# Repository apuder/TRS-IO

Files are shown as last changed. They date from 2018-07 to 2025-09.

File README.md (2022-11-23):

# TRS-IO

TRS-IO gives a TRS-80 Model 1/III online capabilities and provides
access to a variety of services. TRS-IO currently features the
following capabilities:

1. Access to the <a href="https://retrostore.org">RetroStore</a>
2. <a href="http://frehd.com">FreHD</a> emulation
3. Access to files mounted on a SMB share or located on a micro-SD card
4. Access to remote servers via TCP
5. Virtual printer support

The TRS-IO versions for the Model 1 and Model III have some additional features that
are explained below. The following sections give an overview of TRS-IO as well as setup
instructions. This Github repository contains the complete source code
as well as the KiCad schematics for the PCB (Printed Circuit Board).
For the following descriptions it is assumed that an assembled TRS-IO
card is available.

### Overview

The figure below depicts the overall architecture. The TRS-80 machine
is connected to TRS-IO via the I/O bus.  TRS-IO has a WiFi module that
connects to the local WiFi router. This allows TRS-IO to connect to
the Internet and access various services. Note that TRS-IO can only
connect to a 2.4 GHz WiFi network. It is recommended to use an IPEX
antenna to improve WiFi reception.

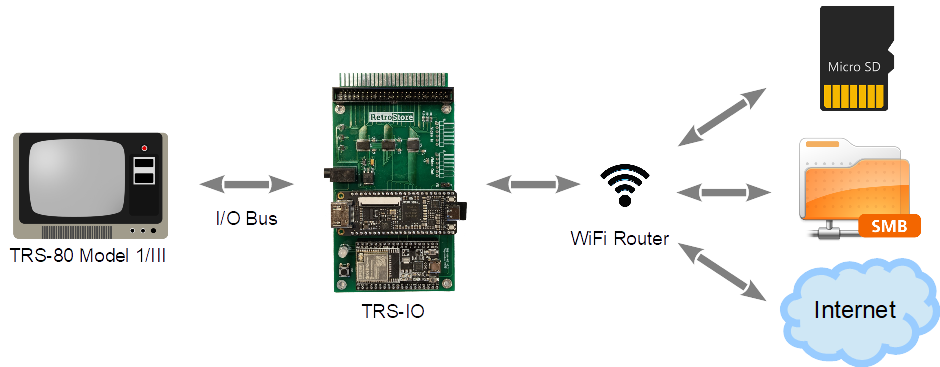
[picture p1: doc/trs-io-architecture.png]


### Prerequisites

TRS-IO requires a TRS-80 Model III with 48kB of RAM or a Model 1 with 16kB of RAM.
Floppy disk drives or a cassette tape are not required.

### Power Supply

There are two versions of TRS-IO that are tailored to the Model 1 and Model III. Each version makes use of an ESP32 microcontroller
as well as a Tang Nano 9K FPGA. Both the ESP32 microcontroller as well as the Nano 9K need to be powered. There are two ways of doing
this.

* Power each module independently via two USB cables that connect to the ESP32's micro-USB and the Nano 9K's USB-C connector.
  For this option, the "VU" jumper (mentioned below), <b>SHOULD NOT BE USED</b>.
* Power the ESP32 via the Nano 9K or vice versa. For this option, only one of the modules need to be provided with power. This option
  requires the "VU" jumper.
  
In the following, each variant of TRS-IO is explained in detail.

### TRS-IO for the Model III

The following figure shows the top view of the TRS-IO card for the Model III:

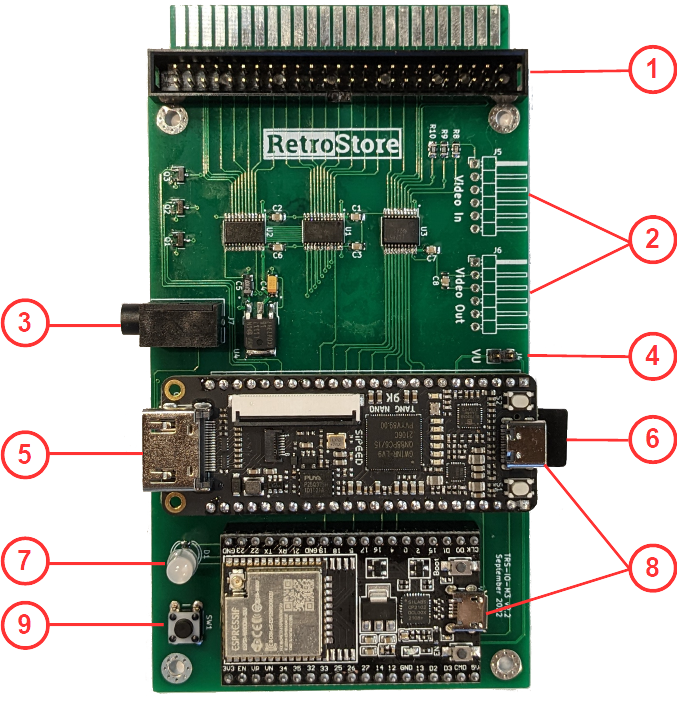
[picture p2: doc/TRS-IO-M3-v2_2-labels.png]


1. 50-pin I/O bus connector
2. High resolution graphics connector
3. 3.5mm audio jack
4. VU jumper
5. HDMI connector
6. Micro-SD card reader
7. Multi-color status LED
8. Micro-USB and USB-C connector
9. Status button

The TRS-IO card needs to be connected to the TRS-80 Model III's I/O
bus via a 50-pin ribbon cable (1). Furthermore, the TRS-IO card needs
a separate power supply via a standard 5V USB charger. Please refer
to the previous section regarding the power supply. The status button
(9) and the multi-color status LED (7) will be explained in the
configuration section. The micro-SD card reader is underneath the
Nano 9K module (6). The 3.5mm audio jack (3) can be connected to a standard
speaker for game sound and Orchestra 90 support. If the high resolution
connectors (2) are connected to the TRS-80, the HDMI connector (5) will
generate a video signal.

### TRS-IO for the Model 1

The following figure shows the top view of the TRS-IO card for the Model 1:

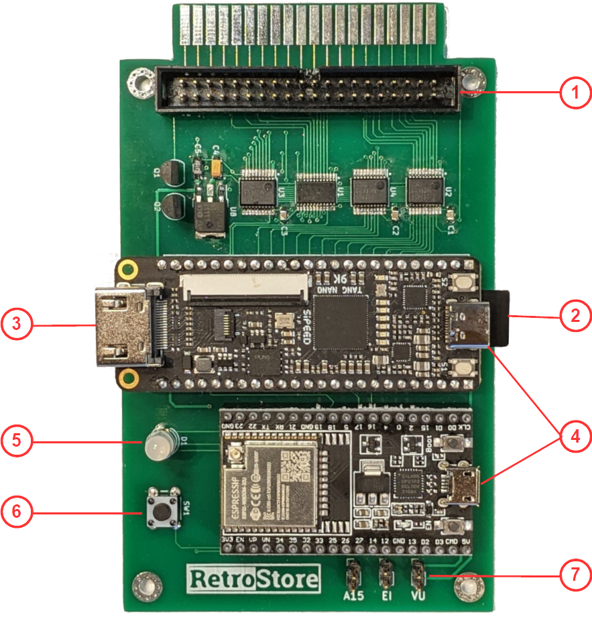
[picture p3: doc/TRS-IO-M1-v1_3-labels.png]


1. 40-pin I/O bus connector
2. Micro-SD card reader
3. HDMI connector
4. Micro-USB and USB-C connector
5. Multi-color status LED
6. Status button
7. VU jumper

The TRS-IO version for the Model 1 features a 40-pin connector that can
directly be connected via a ribbon cable to the I/O bus of a Model 1.
This version of TRS-IO offers the following features:

* HDMI signal of the M1's video screen that includes game sound.
* Upper 32kB RAM (emulated by the Nano 9K FPGA) for a total of 48kB of total RAM.
* 25ms heartbeat timer to trigger the realtime clock.
* FreHD auto-boot for an unmodified M1.

The HDMI connector (3) can be used instead of a CRT monitor. TRS-IO for the M1
also emulates the LE18 graphics cards. The color of the HDMI signal can
be set to white (X=0), green (X=1), and amber (X=2) via the following OUT statements:

```OUT 31,0:OUT 31,5:OUT 31,X```

Please refer to an earlier section on how to provide power to TRS-IO.

### Configuring TRS-IO

The core of the TRS-IO card is an ESP32 microcontroller that features
a WiFi module that is used to connect to a WiFi router. After
physically connecting the TRS-IO card to a TRS-80 Model 1/III as
explained in the previous sections, the WiFi module on the ESP32
microcontroller first needs to be be configured with the credentials
of the local WiFi network.

While in setup mode, the TRS-IO's status LED will continuously blink
in white to indicate that it has not yet been configured. While in
that mode, TRS-IO will create an open access point called
"TRS-IO". Use a laptop to connect to this WiFi network and then use a
browser to visit URL <a
href="http://trs-io.local">trs-io.local</a>. The following web page
should appear in the browser:

<img src="doc/trs-io-web-ui.png" width="50%" />

Some hosts do not correctly handle mDNS that is used to resolve <a
href="http://trs-io.local">trs-io.local</a>. In that case, visit the
IP address <a href="http://192.168.4.1">192.168.4.1</a> instead.
The web interface shown above can be used to configure SSID and password of the WiFi
network that TRS-IO should connect to, the local timezone as well as
the credentials of a SMB share. For open networks leave the WiFi
password field empty. Note that TRS-IO cannot connect to WiFi networks
that use a capture portal. The timezone as well as the SMB share are
not required but will result in limited functionality.

Once all the information is provided, click on submit to upload the
parameters. TRS-IO will automatically reboot and try to connect to the
specified WiFi network. If successful, the LED will turn green for a
few seconds. If the credentials are wrong or if the specified WiFi
network is not accessible, the LED light will turn permanently red.

Note that TRS-IO will store all parameters in its local flash memory,
so the setup only needs to be performed once. Once TRS-IO is connected
to a WiFi router, it should still be possible to access URL <a
href="http://trs-io.local">trs-io.local</a> from a browser on the same
WiFi network. If mDNS is not supported by the host, the following BASIC
program can be used to determine TRS-IO's local IP address that was
assigned by the router:

```
10 OUT 236,16
20 OUT31,0:OUT31,4
30 C=INP(31):IF C=0 THEN END
40 PRINT CHR$(C);
50 GOTO 30
```

The web interface will also display two icons to indicate the status
of the SMB share and the micro-SD card (see screenshot above). Green
icons indicate that TRS-IO has access. Red icons indicate an error.
In that case, hovering the mouse over the red icon will display the
error message. It should be noted that TRS-IO needs to be rebooted
whenever a micro-SD card is inserted or ejected.

Pushing the status button will make the LED flash twice. The first time for
the WiFi status (green: WiFi connected; red: WiFi not connected) and a
second time for the SMB status (green: connected to SMB share; red:
not connected to SMB share). With proper configuration parameters, the
LED should flash green twice. Holding down the push button for more
than three seconds will erase all configuration parameters and place
TRS-IO back into setup mode (status LED flashing white). This
might be necessary if TRS-IO is moved to a different WiFi network.

The status LED indicates the state of TRS-IO:

* Blinking white: TRS-IO is not configured. It will create an open WiFi access point named "TRS-IO"
* Solid green: when TRS-IO has been configured with WiFi credentials and TRS-IO was able
  to connect to the WiFi network, the status LED will light in solid green for several seconds.
* Solid red: TRS-IO was configured with WiFi credentials but it was not possible to connect to the specified
  network. The reason could be wrong credentials or the specified network is itself offline. The push button can be
  used to reset TRS-IO into setup mode in case different credentials need to be provided.
* Solid blue: TRS-IO performs an OTA (Over-the-Air) update. TRS-IO will automatically detect
  newer firmware versions and will download and install the new firmware. The status LED will light solid blue during
  this process.
* Off: the status LED will be off during regular operations when TRS-IO is connected to the specified
  WiFi network and ready to accept commands from the TRS-80 Model III.
 
### FreHD

TRS-IO is compatible with the popular <a
href="http://frehd.com">FreHD</a> hard disk emulator. The FreHD disk
images can either be stored on a SMB share or on a micro-SD card.
If a micro-SD card is inserted, it will take precedence over
a mounted SMB share. Once TRS-IO is configured to access a SMB share,
simply copy the required files such as <a
href="http://members.iinet.net.au/~ianmav/trs80/downloads.htm">FREHD.ROM</a>
to the SMB share. Alternatively, the disk images can be transferred
to the micro-SD card. The IMPORT/EXPORT utilities will access files on the
SMB share or micro-SD card respectively.

### Virtual Printer Interface

TRS-IO support a virtual printer interface. Visiting <a
href="http://trs-io.local/printer">trs-io.local/printer</a> from a browser
will open the printer interface. Any printer output from the M1/MIII will
be displayed in the printer interface. If the host cannot resolve the mDNS name
trs-io.local, the above BASIC program can be used to determine the TRS-80's
IP address.

 ### Launching the native RetroStore Client

The <a href="https://retrostore.org">RetroStore</a> hosts applications
for the Tandy Radio Shack vintage computers and allows to seamlessly
download and run these applications without the need of cassettes or
floppy disks. TRS-IO acts as a gateway to the <a
href="https://retrostore.org">RetroStore</a>. This requires to run a
program on the TRS-80 that interfaces with TRS-IO. This program is
available as a regular <a
href="https://github.com/apuder/TRS-IO/raw/master/src/esp/components/retrostore/rsclient.cmd">CMD</a>
executable.  For TRS-80 machines with attached physical floppy disks,
this CMD executable can be copied to a floppy disk and launched the
usual way. For TRS-80 machines that have neither floppy disk drives
nor cassette drives, it is also possible to bootstrap the native
client via the following short BASIC program:
 
 ```BASIC
 10 OUT236,16
 20 OUT31,3
 30 OUT31,1
 40 N=INP(31)+256*INP(31)
 50 FOR X=1 TO N:POKE20735+X,INP(31):NEXT
 RUN
 SYSTEM
 *? /20736
 ```
 
The above BASIC program will download the CMD executable from TRS-IO
and launch the native client.  Note that this procedure needs to be
repeated every time the TRS-80 is turned on.
 
### Using the native RetroStore Client

After successfully launching the native RetroStore client, the monitor
of the TRS-80 should look like this:
 
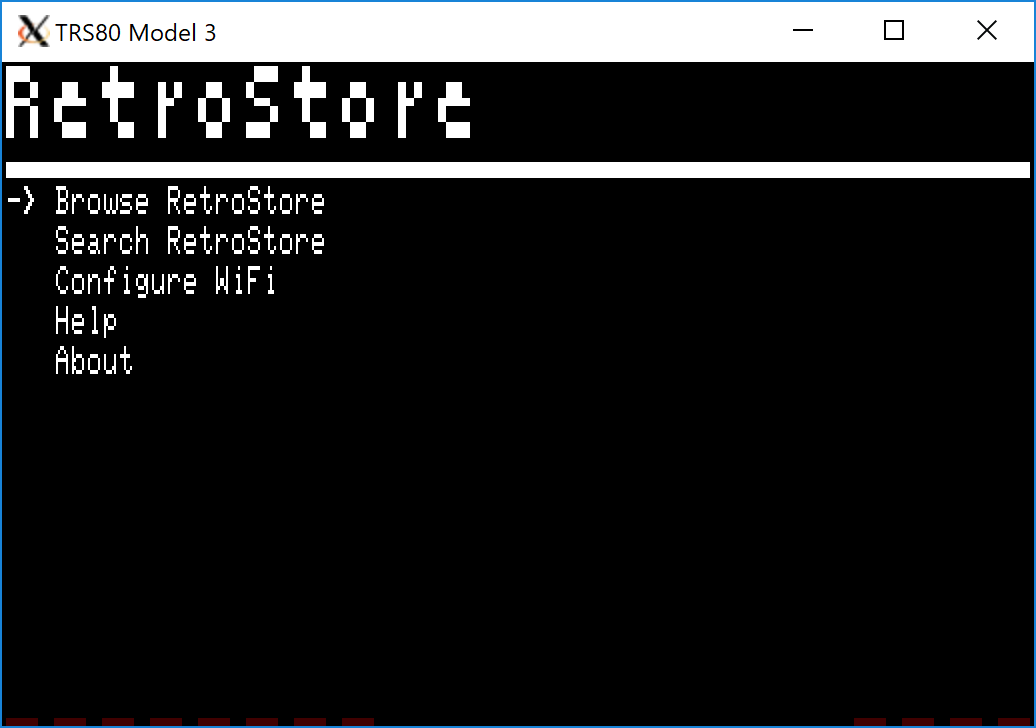
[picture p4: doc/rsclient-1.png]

 
The screenshot above shows the main menu of the native RetroStore
client. The arrow indicates the currently selected menu item.  The up
and down cursor keys can be used to move between the various menu
items. Hitting the ENTER key will activate the currently selected
menu item. Pressing CLEAR or BREAK in sub-menus will return to the
previous menu.
 
Keyboard controls:
 
 * Cursor up/down: toggle menu selection
 * ENTER: select current menu selection
 * BREAK/CLEAR: exit to previous screen

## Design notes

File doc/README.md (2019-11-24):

### TRS-IO Documentation

[TCP/IP](tcp_ip.md) - details about the tsrnic TCP/IP API implemented by TRS-IO

[BOM](build.md) - a detailed list of all components you need to build a TRS-IO board

[Old Board Fix](rs_fix.md) - bodge wire updates to make the original RS board compatible with TRS-IO

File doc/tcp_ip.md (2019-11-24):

# trsnic
## TCP/IP Socket API

### A lightweight TCP/IP networking API

This API provides a subset of the standard TCP/IP Berkeley Sockets API with just enough functionality to create functioning TCP/IP client applications for the TRS-80. We attempt to adhere to the conventions of the Unix standard sockets library found in <sys/types.h> and <sys/socket.h>.  All API calls are sent to the Z80 I/O port 31 as a sequence of bytes where the socket function is represented by a single byte code.  Other parameters are defined as bytes per the specification below.  Responses for each function are read from the same port 31.

For a thorough course on socket programming, read the bible of TCP/IP Sockets Programming [Unix Network Programming by W. Richard Stevens](https://www.amazon.com/Unix-Network-Programming-Sockets-Networking/dp/0131411551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)

For a quicker tutorial on using sockets, see <https://www.tutorialspoint.com/unix_sockets/socket_core_functions.htm>

Only TCP streaming sockets are supported at this time.  UDP socket support will be in an upcoming release.  TLS sockets will also be implemented at some time in the future.

### API Details

#### SOCKET (0x01)

Open a socket. 

**Unix:** int socket (int family, int type, int protocol);

Family: AF\_INET, AF\_INET6 (not currently supported)

Types: SOCK\_STREAM, SOCK\_DGRAM (not currently supported)

Protocols: Defaults to TCP for SOCK\_STREAM and UDP for SOCK\_DGRAM (not currently supported)

This call consists of 4 bytes sent in sequence to the trsnic 
port:

`<TCPIP><SOCKET><FAMILY><TYPE>`

TCPIP = 0x1

SOCKET = 0x01

AF\_INET = 0x01 or AF\_INET6 = 0x02 (*AF\INET6 not yet supported*)

SOCK\_STREAM = 0x1 or SOCK\_DGRAM = 0x02 (*SOCK\_DGRAM not yet supported*)

**Example:** To open a TCP streaming socket, you would send 4 bytes to port 31

<0x01><0x01><0x01><0x01>

**Response:** 2 bytes are returned. The first byte is status (1 for error, 0 for success). On success, the second byte is the socket file descriptor, aka sockfd.  This sockfd should be saved as it will be used by the other socket API functions below.  The second byte is set to errno only when there is an error.

**Example**
Success returns <0x00><0x02> where byte 1 = success and byte 2 = sockfd (in this case the integer 2)
Failure returns <0x01><0x01> where byte 1 = error and byte 2 = errno (in this case 1)

#### CONNECT (IP-ADDRESS) (0x02)

Connect to a server socket using an IP address.  Only used for streaming sockets, ie. TCP SOCK_STREAM

**Unix**: int connect(int sockfd, struct sockaddr *serv_addr, int addrlen);

CONNECT with IP address consists of 10 bytes (for an IPv4 address) to send to the trsnic port.  Use 1 byte for the protocol, 1 byte for the command code, 1 byte for the sockfd, 1 byte for the host format (0x00 for IP address), 4 bytes for IPv4 addresses (or 6 bytes for IPv6 addresses, not currently supported) and a 2 byte port sent in network order.

`<TCPIP><CONNECT><SOCKFD><0x00><IP4><IP3><IP2><IP1><PORT LSB><PORT MSB>`

where 

TCPIP = 0x01

CONNECT = 0x02

SOCKFD = the socket descriptor returned from SOCKET

HOST FORMAT = 0x00 (0 indicates IP address)

IP4 = 0x00 to 0xFF

IP3 = 0x00 to 0xFF

IP2 = 0x00 to 0xFF

IP1 = 0x00 to 0xFF

PORT1 = 0x00 to 0xFF  LSB of 16bit port number 

PORT2 = 0x00 to 0xFF  MSB of 16bit port number 

**Example:** To connect to port 23 on a server listening on IP address 192.168.1.100

`<0x01><0x02><SOCKFD><0xC0><0xA8><0x01><0x64><0x17><0x00>`

#### CONNECT (HOSTNAME) (0x03)

CONNECT with a hostname consists of a series of bytes to send to the trsnic port.  Use 1 byte for the protocol, 1 byte for the command code, 1 byte for the sockfd, 1 byte for the host format(0x01 for hostname), the hostname in ASCII bytes followed by a NULL (0x00) (to indicate the end of the hostname) and ends with a 2 byte port sent in network order.

`<TCPIP><CONNECT><SOCKFD><0x01><HOSTNAME><NULL><PORT LSB><PORT MSB>`

where 

TCPIP = 0x01

CONNECT = 0x03

SOCKFD = the socket descriptor returned from SOCKET

HOSTNAME = a sequence of ASCII bytes representing any valid hostname resolvable by your network DNS (e.g. www.google.com)

NULL = 0x00 (marks the end of the hostname string)

PORT1 = 0x00 to 0xFF  LSB of 16bit port number 

PORT2 = 0x00 to 0xFF  MSB of 16bit port number 

**Example:** To connect to port 23 on a server with hostname pski.net

`<0x01><0x03><SOCKFD><0x70><0x73><0x6B><0x69><0x2E><0x6E><0x65><0x74><0x00><0x17><0x00>`

**Response:** 1 or 2 bytes are returned. The first byte is 1 for error, 0 for success.  The second byte is set to errno only when there is an error.

**Example:** Success returns `<0x00>` where byte 1 = success
Failure returns `<0x01><0x01>` where byte 1 = error and byte 2 = errno

#### SEND (0x04)

Sends data over the socket.

**Unix:** int send(int sockfd, const void *msg, int len, int flags);

SEND consists of a 7 byte header and L bytes of data.

`<TCPIP><SEND><SOCKFD><L1><L2><L3><L4><DATA...>`

SOCKFD = the socket descriptor returned from SOCKET

L1-L4 = the length of the data specified as 4 bytes.  This is in little endian order where L1 is the LSB and L4 is the MSB.  The theoretical maximum length of data in one send is 2,147,483,647 bytes.

DATA = a sequence of bytes of length len

**Example:** 

`<0x01><0x04><0x01><0x05><0xFF><0x00><0x00><0xFF><0xFF>....<0xFF>` 
where byte 1 = TCPIP, byte 2 = SEND, byte 3 = SOCKFD, bytes 4 to 7 = data length of 260 and bytes 8 to (data length+8) are the data bytes.

**Response:** a 1 byte success flag (1 for error, 0 for success), followed by 4 byte response with the length of data actually sent on success or single byte errno on error.

**Example.** `<0x00><0x05><0xFF><0x00><0x00>` where byte 1 = success and bytes 2 to 5 = 32 bit data length of 260.
or
`<0x01><0x06>` where byte 1 = error and byte 2 = errno 

#### SENDTO (0x05) (*Not yet supported*)

Sends a UDP datagram over the socket.

**Unix:** int send(int sockfd, const void *msg, int len, int flags);

#### RECV (0x06)

Receive data from the socket.  Use only for connection oriented sockets ie. TCP.

**Unix:** int recv(int s, void *buf, size_t len, int flags);

`<TCPIP><RECV><SOCKFD><OPTION><L1><L2><L3><L4>`

TCPIP = 0x01

RECV = 0x06

SOCKFD = the socket descriptor returned from SOCKET

OPTION (0 - blocking, 1 - nonblocking)

L1-L4 = the maximum length of the data to read specified as 4 bytes.  The maximum length of data in one receive is 64K.

**Example:**
`<0x01><0x06><0x01><0x01><0x05><0xFF><0x00><0x00>` where byte 1 = TCPIP, 2 = RECV, 3 = OPTION, byte 4 = SOCKFD, bytes 5 to 8 = max data length to received with this request in LE order.

**Response:** a 1 byte success flag (1 for error, 0 for success), followed by 4 byte response with the 32 bit length of data followed by the data bytes.
On error only 2 bytes are returned. The first byte is 1 for error, 0 for success.  The second byte is set to errno when there is an error.

**Example:** `<0x00><L1><L2><L3><L4><DATA...>`
or
`<0x01><0x6>` where byte 1 = error and byte 2 = errno (in this case 6)

#### RECVFROM (0x07) (*Not yet supported*)

Receive a data gram from the socket.  Use only for connection-less sockets (ie. UDP);

**Unix:** int recvfrom(int s, void *&ast;buf*, size\_t *len*, int *flags*, struct sockaddr *&ast;from*, socklen\_t *&ast;fromlen*); 

`<RECVFROM><SOCKFD><IP4><IP3><IP2><IP1><PORT LSB><PORT MSB>`

Returns a 1 byte success flag (1 for error, 0 for success), followed by 4 byte response with the length of data
On error only 2 bytes are returned. The first byte is 1 for error, 0 for success.  The second byte is set to errno when there is an error.

<0x00><L1><L2><L3><L4><DATA...>
or
<0x01><errno>

#### CLOSE (0x08)

Close a socket

**Unix:** int close(int sockfd);

Send 3 bytes to the trsnic port.

`<TCPIP><CLOSE><SOCKFD>`

TCPIP = 0x01

CLOSE = 0x08

SOCKFD = the socket descriptor returned from SOCKET

**Response:** 1 or 2 bytes are returned. The first byte is 1 for error, 0 for success.  The second byte is set to errno only when there is an error.

**Example:**
`<0x00>`
or
`<0x01><0x01>`

-----
Have questions? [@pski](https://github.com)

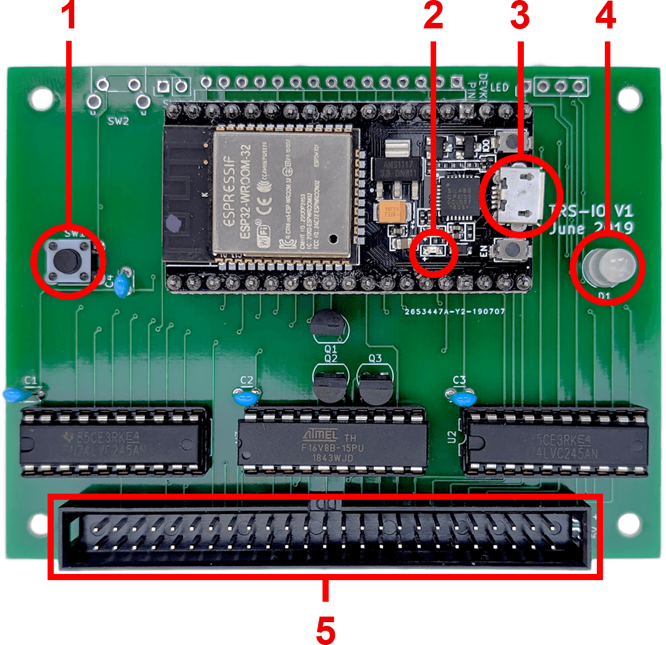
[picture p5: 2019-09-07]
doc/trs-io-card-v1-labels.png

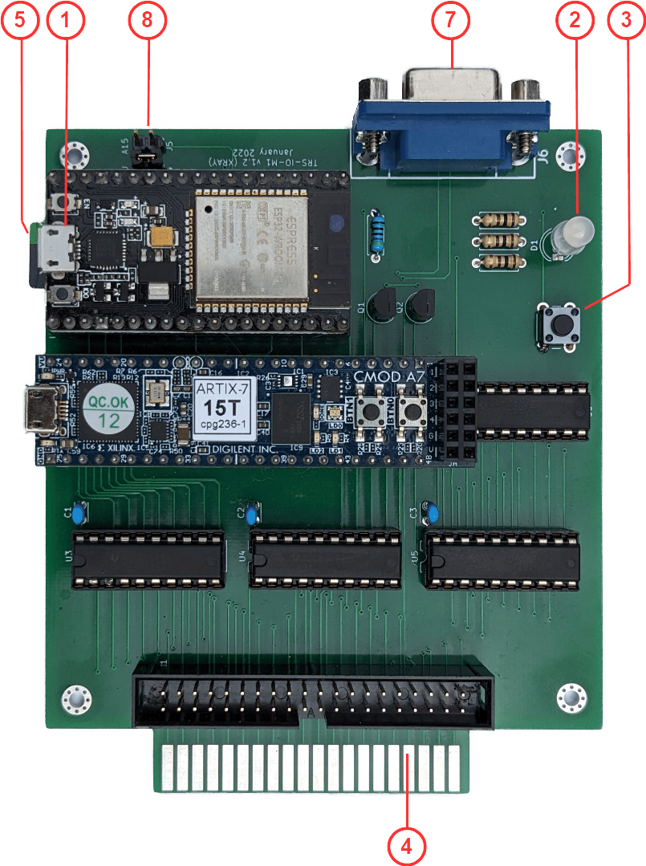
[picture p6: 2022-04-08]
doc/TRS-IO-M1-XRAY-labels.png

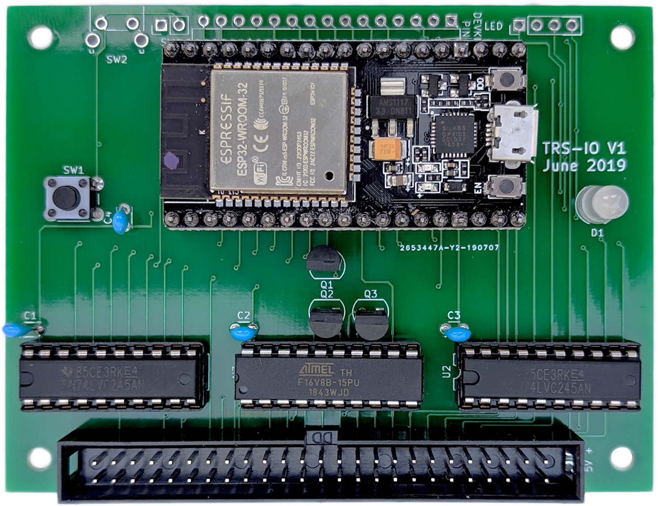
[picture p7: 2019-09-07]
doc/trs-io-card-v1.png

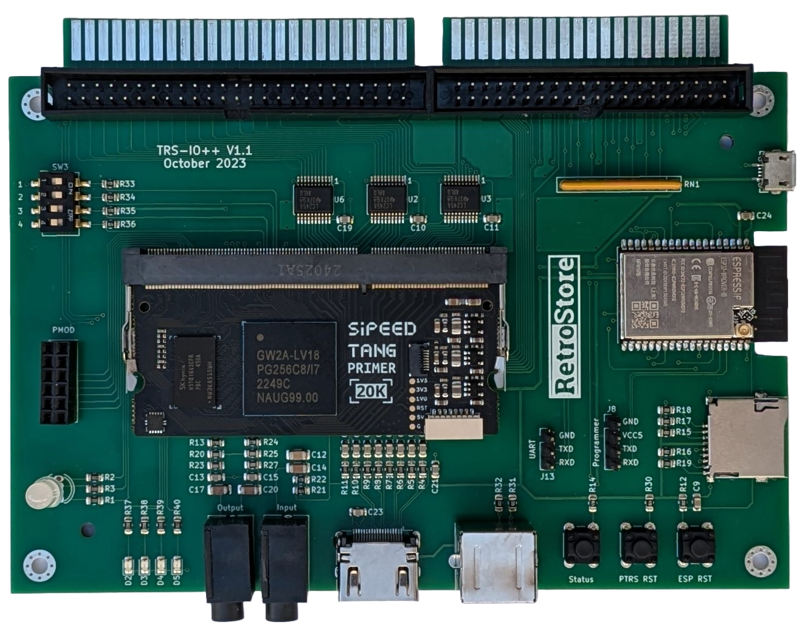
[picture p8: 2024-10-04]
doc/TRS-IO-PP-v1_1.png

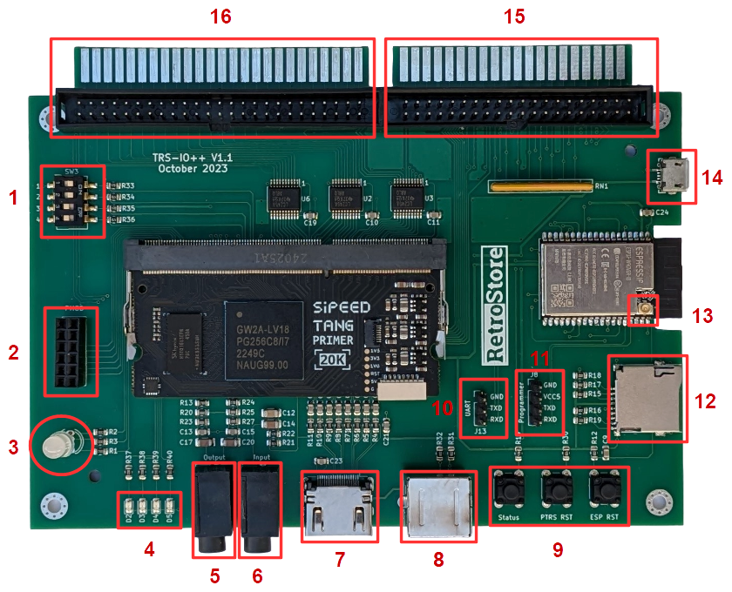
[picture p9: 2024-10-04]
doc/TRS-IO-PP-v1_1-labels.png

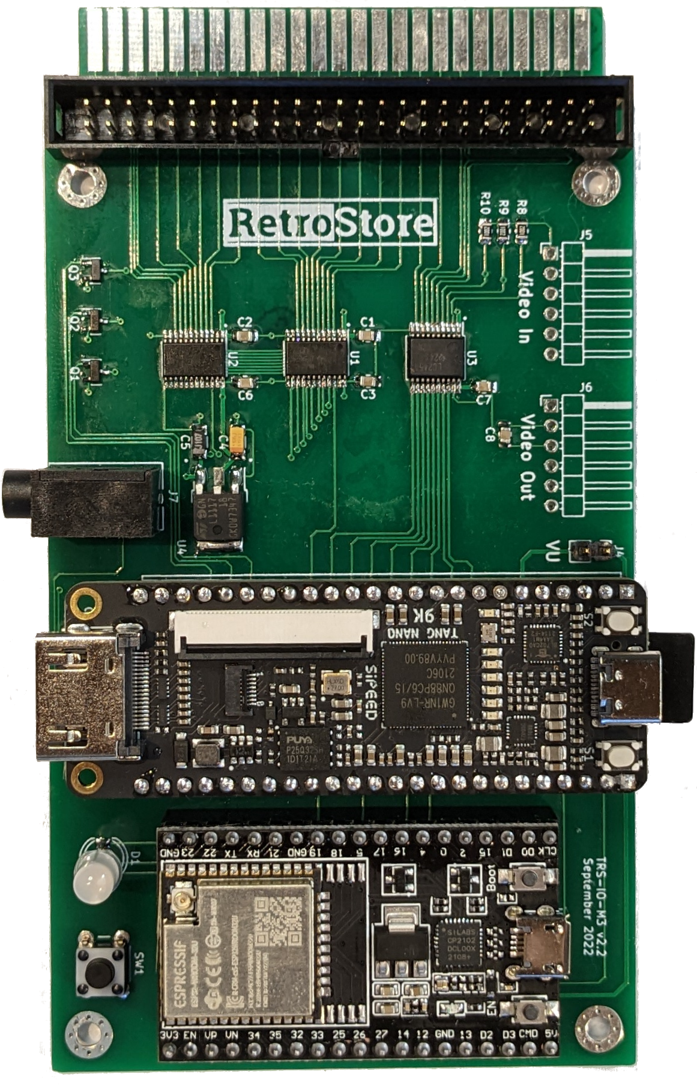
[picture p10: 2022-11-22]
doc/TRS-IO-M3-v2_2.png

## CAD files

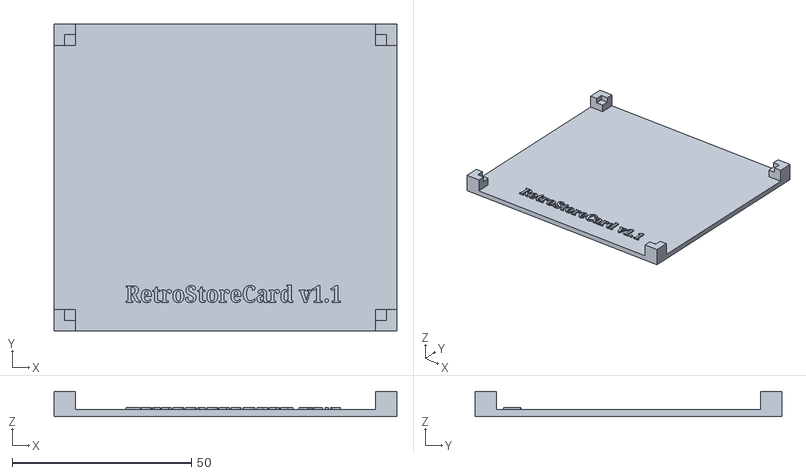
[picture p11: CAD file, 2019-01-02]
3d/pcb_case.stl
95.7 x 85.8 x 7.00

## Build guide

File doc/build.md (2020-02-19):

#### TRS-IO - Circuit Board Bill of Materials

|Qty|Ref|Digikey Part#|Manuf Part #|Description|
|:---|:---|:---|:---|:---|
|1|U1||ESP32 MODULE|Refer to Supported ESP32 Modules
|1|U3|[ATF16V8B-15PU-ND](https://www.digikey.com/product-detail/en/microchip-technology/ATF16V8B-15PU/ATF16V8B-15PU-ND/1118926)|ATF16V8B-15PU|IC PLD 8MC 15NS 20DIP
|2|U2,U4|[296-8503-5-ND](https://www.digikey.com/product-detail/en/texas-instruments/SN74LVC245AN/296-8503-5-ND/377483)|SN74LVC245AN|IC TXRX NON-INVERT 3.6V 20DIP
|3|Q1,Q2,Q3|[2N7000-G-ND](https://www.digikey.com/product-detail/en/microchip-technology/2N7000-G/2N7000-G-ND/4902350)|2N7000-G|MOSFET N-CH 60V 0.2A TO92-3
|1|D1|[1830-1014-ND](https://www.digikey.com/product-detail/en/inolux/HV-5RGB60/1830-1014-ND/7604616)|HV-5RGB60|LED RGB DIFFUSED 5MM T/H
|1|SW1|[450-1650-ND](https://www.digikey.com/product-detail/en/te-connectivity-alcoswitch-switches/1825910-6/450-1650-ND/1632536)|1825910-6|SWITCH TACTILE SPST-NO 0.05A 24V
|1|SW2||1825910-6|SWITCH TACTILE RIGHT-ANGLE SPST-NO 0.05A 24V
|3|U2,U3,U4|[ED3054-5-ND](https://www.digikey.com/product-detail/en/on-shore-technology-inc/ED20DT/ED3054-5-ND/4147598)|ED20DT|CONN IC DIP SOCKET 20POS TIN
|1|J1|[ED10530-ND](https://www.digikey.com/product-detail/en/on-shore-technology-inc/302-S501/ED10530-ND/2794241)|302-S501|CONN HEADER VERT 50POS 2.54MM
|1||[HDR100IMP40F-G-V-TH-ND](https://www.digikey.com/product-detail/en/chip-quik-inc/HDR100IMP40F-G-V-TH/HDR100IMP40F-G-V-TH-ND/5978200)|HDR100IMP40F-G-V-TH|SIL HDR 40POS 0.1 GOLD PCB
|4|C1,C2,C3,C4|[490-8809-ND](https://www.digikey.com/short/pvj15w)|RDER71E104K0P1H03B|CAP CER 0.1UF 25V X7R RADIAL
|3|R1,R2,R3|||100R 0.25W
|1|R4|||4K7 0.25W

#### Supported ESP32 Modules:
The TRS-IO board supports two commonly available ESP32 modules.

* 38 Pin Module commonly branded as NodeMCU or HiLetGo

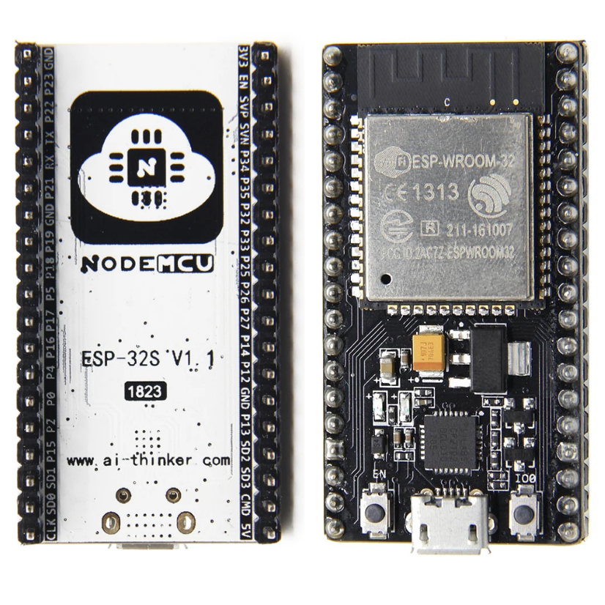
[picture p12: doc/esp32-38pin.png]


* 30 Pin Module commonly branded as DEVKITV1

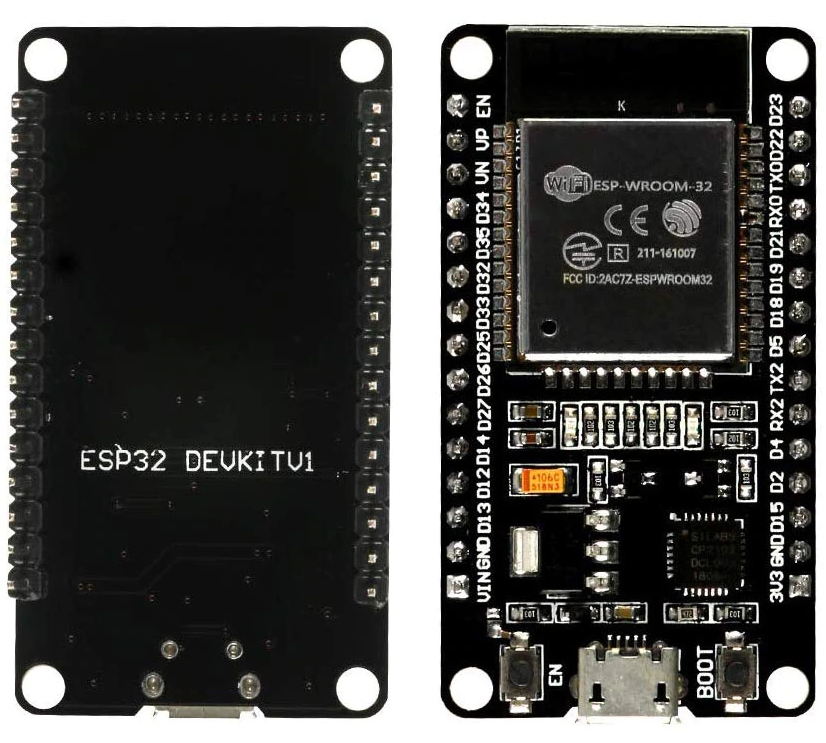
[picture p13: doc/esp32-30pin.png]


The pinout and spacing of the two modules differs.  Unless you plan to test your board with both modules, install 15 pin SIL sockets in 1st and 3rd positons for the 30 Pin Module or 19 pin SIL sockets in the 2nd and 4th positions for the 38 Pin Module.

Correct orientation of the modules is shown below:

* 38 Pin Module commonly branded as NodeMCU or HiLetGo

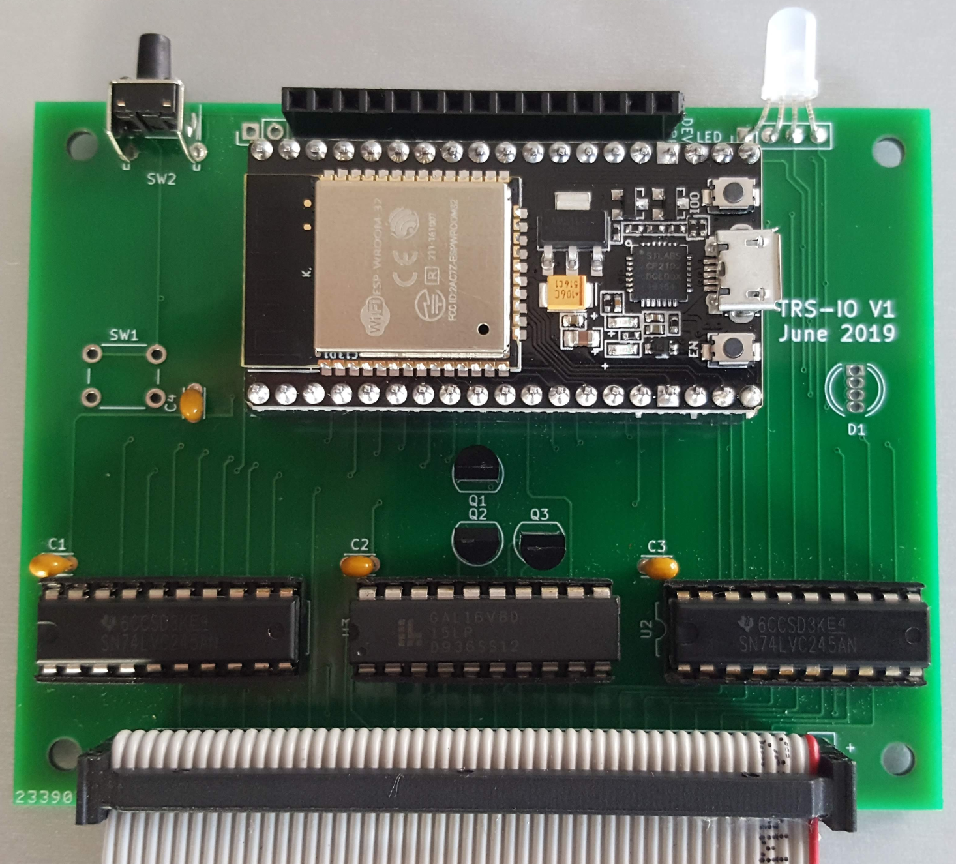
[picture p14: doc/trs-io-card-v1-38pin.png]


* 30 Pin Module commonly branded as DEVKITV1

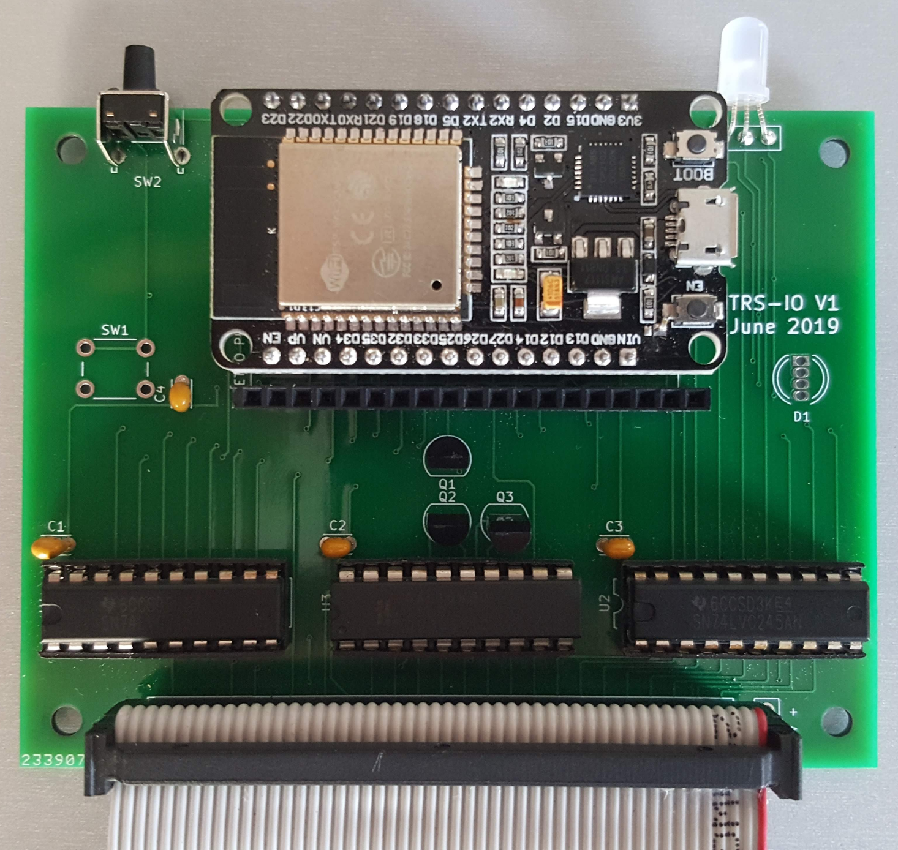
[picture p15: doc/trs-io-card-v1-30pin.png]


#### Notes:
* The switch can be installed in either SW1 or SW2.  SW2 is recommended when assembling the board for installation in a case.
* The LED can be installed in either D1 or J4.  J4 is recommended when assembling the board for installation in a case.  Do not install an LED in both D1 and J4.
* R1,R2 and R3 are current limiting resistors for the LED.  The values are not critical and may require adjustment for some LED.
* The J5 header can be installed and jumpered to disable the internal FreHD emulation when an external FreHD is connected to the expansion connector.  J5 can be omitted if an external FreHD is not used.
* R4 is a pullup for the ESP32 FreHD Inhibit signal. This must always be installed even J5 is not.  Value is not critical.  Anything between 4K7 and 10K will work.
* 5V can be connected to J5 as an alternative to powering ESP32 from USB.  This is recommended when assembling the board for installation in a case.

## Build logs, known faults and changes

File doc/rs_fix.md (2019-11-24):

### RetroStoreCard Wiring Fix

If you have the original RetroStoreCard it can be made compatible with TRS-IO by adding a number of bodge wires.

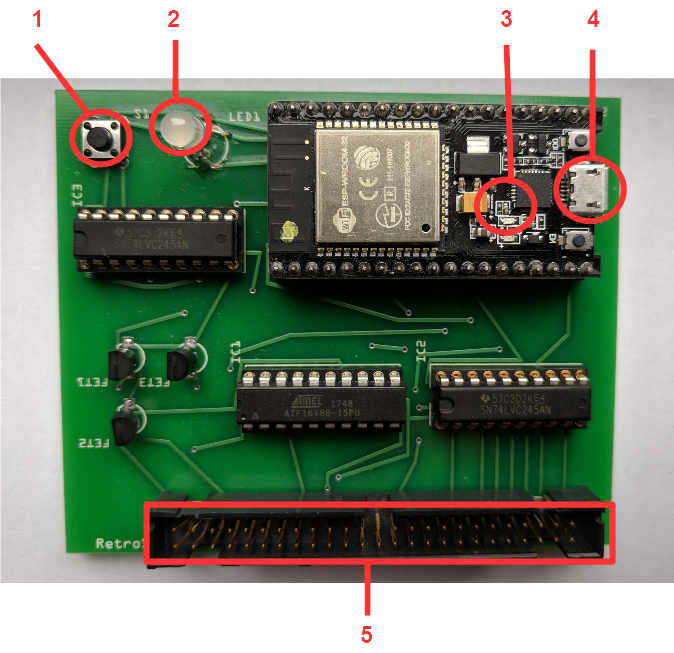
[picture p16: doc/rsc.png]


The original RetroStoreCard looks like the one above.  If you have one of these, then you need to add the following wire connections to bring it up to spec with TRS-IO.

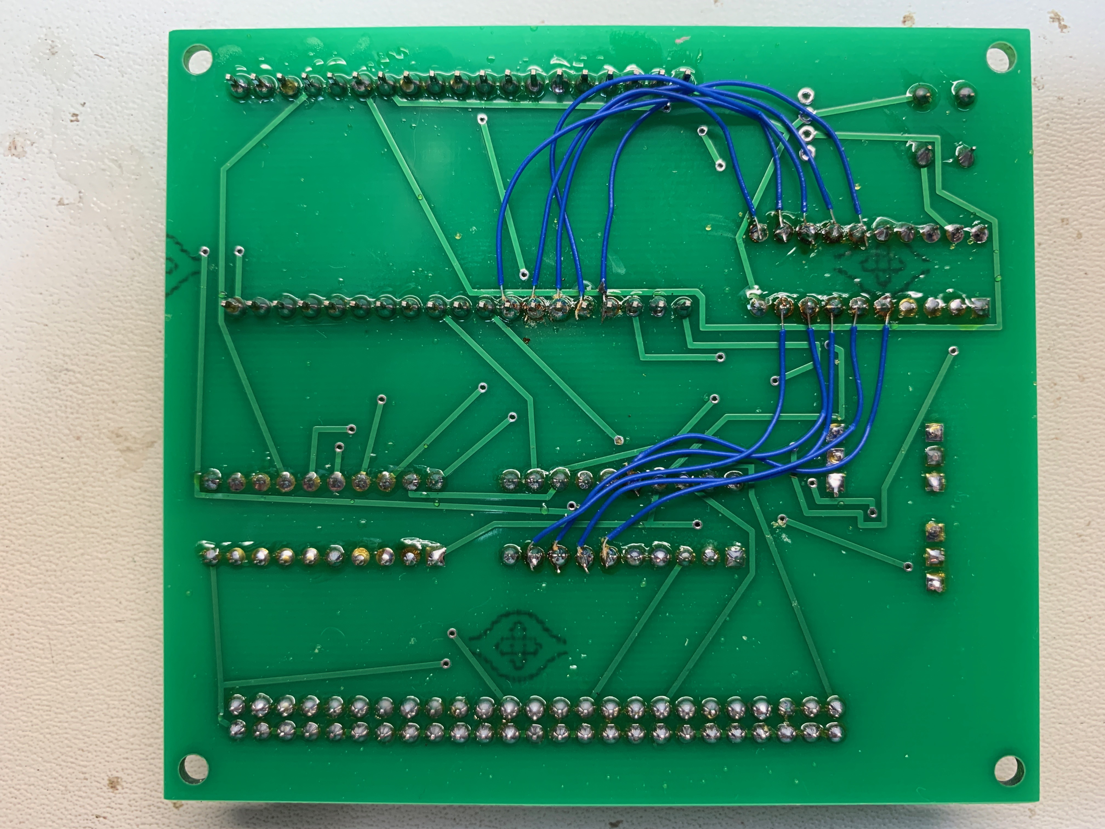
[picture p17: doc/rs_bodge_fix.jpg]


#### Wire Table

|From |To|
|:---|:---|
|ESP 23| IC3 15
|ESP 24| IC3 13
|ESP 25| IC3 14
|ESP 26| IC3 11
|ESP 27| IC3 12
|IC1 6| IC3 5
|IC1 7| IC3 7
|IC1 8| IC3 8
|IC1 9| IC3 9
|IC1 16| IC3 5

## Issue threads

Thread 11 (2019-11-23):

Capacitors on new PCB

pski, 2019-11-23:
What are the specs for the capacitors C1-C4 on the new PCB?  It appears all the other components are identical to the RS card, correct?

apuder, 2019-11-23:
0.1uF: https://www.digikey.com/short/pvj15w
And yes, all other components are identical to the original RSC.

Closed 2019-11-23.

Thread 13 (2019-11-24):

Resistors R1, R2 and R3

pski, 2019-11-24:
I just noticed there are 3 new resistors on the TRS-IO board, R1, R2 and R3.  What are the specs for these?

apuder, 2019-11-25:
I was a little lazy with the design of the RSC and didn't include any resistor for the multi-color LED. The 3.3V don't kill the LED. For TRS-IO @jaquinn added resistors for the RGB pins. Some small value (e.g., 100 Ohms) should be fine.

Closed 2019-11-25.

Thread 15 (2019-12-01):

dram0_0_seg size DRAM segment data does not fit.

johnwiggins, 2019-12-01:
Sorry, yet another problem loading:

LD esp/build/trs-io.elf
/home/wiggins/xtensa-esp32-elf/bin/../lib/gcc/xtensa-esp32-elf/5.2.0/../../../../xtensa-esp32-elf/bin/ld: /home/wiggins/TRS-IO/src/esp/build/trs-io.elf section `.dram0.bss' will not fit in region `dram0_0_seg'
/home/wiggins/xtensa-esp32-elf/bin/../lib/gcc/xtensa-esp32-elf/5.2.0/../../../../xtensa-esp32-elf/bin/ld: DRAM segment data does not fit.
/home/wiggins/xtensa-esp32-elf/bin/../lib/gcc/xtensa-esp32-elf/5.2.0/../../../../xtensa-esp32-elf/bin/ld: region `dram0_0_seg' overflowed by 22872 bytes

apuder, 2019-12-01:
Now this is weird. Can you please answer a few quick questions?
- Which version of the Espressif SDK did you use?
- Did you make any modifications to sdkconfig?
- Did you make any modifications to the code of TRS-IO?

johnwiggins, 2019-12-01:
I used esp-idf 3.2.2 because the latest Git version (4?) wouldn't build the TRS-IO sources at all. The  extensa compilers are from xtensa-esp32-elf-linux64-1.22.0-80-g6c4433a-5.2.0.tar.gz.

The build was done on a fresh clone of TRS-IO with defaults selected during config. I didnt change anything in the current build tree.

apuder, 2019-12-01:
Which ESP32 variant do you use? As a possible fix, can you change the declarations in rsclient.c to "const"? (the file you were asking about in your other issue). You might have to make a change somewhere else to match the "const" declaration but the compiler will tell you. By declaring the huge array as const will prevent it from being loaded into RAM and might fix your problem. But I'm still a little unsure why I'm not seeing this problem.

johnwiggins, 2019-12-01:
I'm using a Hiletgo ESP32-WROOM-32. Changing the variables in rsclient.c to const worked without having to change anything anywhere else. eg:

 esp]$ make                                                                            
Toolchain path: /home/wiggins/xtensa-esp32-elf/bin/xtensa-esp32-elf-gcc                                
Toolchain version: crosstool-ng-1.22.0-80-g6c4433a                                                     
Compiler version: 5.2.0                                                                                
Python requirements from /home/wiggins/esp/esp-idf/requirements.txt are satisfied.                     
CC build/retrostore/rsclient.o                                                                         
AR build/retrostore/libretrostore.a                                                                    
LD build/trs-io.elf                                                                                    
esptool.py v2.6                                                                                        
To flash all build output, run 'make flash' or:                                                        
python /home/wiggins/esp/esp-idf/components/esptool_py/esptool/esptool.py --chip esp32 --port /dev/ttyS4 --baud
 115200 --before default_reset --after hard_reset write_flash -u --flash_mode dio --flash_freq 40m --flash_size
 detect 0xd000 /home/wiggins/TRS-IO/src/esp/build/ota_data_initial.bin 0x1000 /home/wiggins/TRS-IO/src/esp/buil
d/bootloader/bootloader.bin 0x10000 /home/wiggins/TRS-IO/src/esp/build/trs-io.bin 0x8000 /home/wiggins/TRS-IO/s
rc/esp/build/partitions_two_ota.bin

apuder, 2019-12-01:
Better do a "make clean" to be sure. You should also have to change it here:
https://github.com/apuder/TRS-IO/blob/master/src/esp/components/retrostore/retrostore.cpp#L18

johnwiggins, 2019-12-01:
Make clean worked too, and didn't throw an error from retrostore.cpp.

Was able to load the code from the pre-make clean build and the ESP32 booted, went into config mode and once configured, happily joined my wifi network. Still have to test the rest of the card on a M3, but so far, so good! Thank you and I owe you a beer!

apuder, 2019-12-02:
I still suggest to change the declaration in retrostore.cpp to const as well. Please keep me posted. I'm especially interested in you can get the FreHD part to work. Another user had some issues with that.

johnwiggins, 2019-12-02:
okay changing retrostore.cpp to const breaks things.

CXX build/retrostore/retrostore.o                                                                      
/home/wiggins/TRS-IO/src/esp/components/retrostore/retrostore.cpp: In member function 'void RetroStoreModule::s
endCMD()':                                                                                             
/home/wiggins/TRS-IO/src/esp/components/retrostore/retrostore.cpp:53:47: error: invalid conversion from 'const
void*' to 'void*' [-fpermissive]                                                                       
       addBlob16(rsclient_cmd, rsclient_cmd_len);                                                      
                                               ^                                                               |
In file included from /home/wiggins/TRS-IO/src/esp/components/retrostore/retrostore.cpp:2:0:                   |
/home/wiggins/TRS-IO/src/esp/components/trs-io/include/trs-io.h:192:24: note:   initializing argument 1 of 'sta
tic void TrsIO::addBlob16(void*, uint16_t)'                                                                    |
     inline static void addBlob16(void *blob, uint16_t len) {                                                  |
                        ^                                                                                      |
/home/wiggins/TRS-IO/src/esp/components/retrostore/retrostore.cpp:61:49: error: invalid conversion from 'const
void*' to 'void*' [-fpermissive]                                                                               |
         addBlob16(rsclient_cmd, rsclient_cmd_len);                                                            |
                                                 ^                                                     
In file included from /home/wiggins/TRS-IO/src/esp/components/retrostore/retrostore.cpp:2:0:                   |
/home/wiggins/TRS-IO/src/esp/components/trs-io/include/trs-io.h:192:24: note:   initializing argument 1 of 'sta|
tic void TrsIO::addBlob16(void*, uint16_t)'                                                                    |
     inline static void addBlob16(void *blob, uint16_t len) {
                        ^                                                                                      |
make[1]: *** [retrostore.o] Error 1
make: *** [component-retrostore-build] Error 2

apuder, 2019-12-02:
Well, didn't consider that. Then just declare the array as const in rsclient.c since that seems to work for you. I'll work on a more general fix. Please let me know if you have any issues with FreHD. Thanks!

Closed 2019-12-02.

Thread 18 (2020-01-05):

esp32 app crashes

iceblu3710, 2020-01-05:
I got esp-idf v3.2.2 installed and can load the hello world example successfully.

I ran make in the src folder and was asked a dozen questions I know nothing about. I do know if you select release instead of debug you get compile errors. I stayed with debug and it compiled. I then went to src/esp and did a make menuconfig, set the TTY and then make flash monitor and I get a esp32 program crashing.

````I (5318) cpu_start: Pro cpu up.
I (5318) cpu_start: Starting app cpu, entry point is 0x40081010
0x40081010: call_start_cpu1 at /home/uminded/esp/esp-idf/components/esp32/cpu_start.c:246

I (5304) cpu_start: App cpu up.
D (5321) memory_layout: Checking 7 reserved memory ranges:
D (5327) memory_layout: Reserved memory range 0x3ffae000 - 0x3ffae6e0
D (5333) memory_layout: Reserved memory range 0x3ffb0000 - 0x3ffd8450
D (5340) memory_layout: Reserved memory range 0x3ffe0000 - 0x3ffe0440
D (5346) memory_layout: Reserved memory range 0x3ffe3f20 - 0x3ffe4350
D (5353) memory_layout: Reserved memory range 0x40070000 - 0x40078000
D (5359) memory_layout: Reserved memory range 0x40078000 - 0x40080000
0x40080000: _WindowOverflow4 at /home/uminded/esp/esp-idf/components/freertos/xtensa_vectors.S:1779

D (5366) memory_layout: Reserved memory range 0x40080000 - 0x40090094
0x40080000: _WindowOverflow4 at /home/uminded/esp/esp-idf/components/freertos/xtensa_vectors.S:1779

D (5372) memory_layout: Building list of available memory regions:
D (5379) memory_layout: Available memory region 0x3ffae6e0 - 0x3ffb0000
D (5385) memory_layout: Available memory region 0x3ffd8450 - 0x3ffda000
D (5392) memory_layout: Available memory region 0x3ffda000 - 0x3ffdc000
D (5399) memory_layout: Available memory region 0x3ffdc000 - 0x3ffde000
D (5405) memory_layout: Available memory region 0x3ffde000 - 0x3ffe0000
D (5412) memory_layout: Available memory region 0x3ffe0440 - 0x3ffe3f20
D (5419) memory_layout: Available memory region 0x3ffe4350 - 0x3ffe8000
D (5425) memory_layout: Available memory region 0x3ffe8000 - 0x3fff0000
D (5432) memory_layout: Available memory region 0x3fff0000 - 0x3fff8000
D (5439) memory_layout: Available memory region 0x3fff8000 - 0x3fffc000
D (5445) memory_layout: Available memory region 0x3fffc000 - 0x40000000
D (5452) memory_layout: Available memory region 0x40090094 - 0x40092000
D (5459) memory_layout: Available memory region 0x40092000 - 0x40094000
D (5465) memory_layout: Available memory region 0x40094000 - 0x40096000
D (5472) memory_layout: Available memory region 0x40096000 - 0x40098000
D (5479) memory_layout: Available memory region 0x40098000 - 0x4009a000
D (5485) memory_layout: Available memory region 0x4009a000 - 0x4009c000
D (5492) memory_layout: Available memory region 0x4009c000 - 0x4009e000
D (5499) memory_layout: Available memory region 0x4009e000 - 0x400a0000
I (5506) heap_init: Initializing. RAM available for dynamic allocation:
D (5513) heap_init: New heap initialised at 0x3ffae6e0
I (5518) heap_init: At 3FFAE6E0 len 00001920 (6 KiB): DRAM
D (5524) heap_init: New heap initialised at 0x3ffd8450
I (5529) heap_init: At 3FFD8450 len 00007BB0 (30 KiB): DRAM
I (5536) heap_init: At 3FFE0440 len 00003AE0 (14 KiB): D/IRAM
I (5542) heap_init: At 3FFE4350 len 0001BCB0 (111 KiB): D/IRAM
D (5549) heap_init: New heap initialised at 0x40090094
I (5554) heap_init: At 40090094 len 0000FF6C (63 KiB): IRAM
I (5560) cpu_start: Pro cpu start user code
D (5572) clk: RTC_SLOW_CLK calibration value: 3409152
D (213) intr_alloc: Connected src 46 to int 2 (cpu 0)
D (214) intr_alloc: Connected src 57 to int 3 (cpu 0)
D (215) intr_alloc: Connected src 24 to int 9 (cpu 0)
I (219) cpu_start: Starting scheduler on PRO CPU.
D (0) intr_alloc: Connected src 25 to int 2 (cpu 1)
I (4) cpu_start: Starting scheduler on APP CPU.
D (243) heap_init: New heap initialised at 0x3ffe0440
D (249) heap_init: New heap initialised at 0x3ffe4350
D (254) intr_alloc: Connected src 16 to int 12 (cpu 0)
I (259) gpio: GPIO[4]| InputEn: 0| OutputEn: 1| OpenDrain: 0| Pullup: 0| Pulldown: 1| Intr:0
I (268) gpio: GPIO[5]| InputEn: 0| OutputEn: 1| OpenDrain: 0| Pullup: 0| Pulldown: 1| Intr:0
I (277) gpio: GPIO[21]| InputEn: 0| OutputEn: 1| OpenDrain: 0| Pullup: 0| Pulldown: 1| Intr:0
I (287) gpio: GPIO[22]| InputEn: 1| OutputEn: 0| OpenDrain: 0| Pullup: 1| Pulldown: 0| Intr:3
D (296) intr_alloc: Connected src 22 to int 13 (cpu 0)
D (302) nvs: nvs_flash_init_custom partition=nvs start=9 count=4
D (339) nvs: nvs_open_from_partition retrostore 1
D (341) nvs: nvs_open_from_partition misc 1
D (341) nvs: nvs_get_str_or_blob log
I (342) wifi: wifi driver task: 3ffdfcc0, prio:23, stack:3584, core=0
I (347) wifi: wifi firmware version: 693c7b6
I (351) wifi: config NVS flash: enabled
I (354) wifi: config nano formating: disabled
I (359) system_api: Base MAC address is not set, read default base MAC address from BLK0 of EFUSE
I (368) system_api: Base MAC address is not set, read default base MAC address from BLK0 of EFUSE
D (378) nvs: nvs_open_from_partition nvs.net80211 1
D (383) nvs: nvs_get opmode 1
D (386) nvs: nvs_get_str_or_blob sta.ssid
D (390) nvs: nvs_get_str_or_blob sta.mac
D (394) nvs: nvs_get sta.authmode 1
D (397) nvs: nvs_get_str_or_blob sta.pswd
D (402) nvs: nvs_get_str_or_blob sta.pmk
D (406) nvs: nvs_get sta.chan 1
D (409) nvs: nvs_get auto.conn 1
D (412) nvs: nvs_get bssid.set 1
D (415) nvs: nvs_get_str_or_blob sta.bssid
D (420) nvs: nvs_get sta.lis_intval 2
D (423) nvs: nvs_get sta.phym 1
D (426) nvs: nvs_get sta.phybw 1
D (430) nvs: nvs_get_str_or_blob sta.apsw
D (434) nvs: nvs_get_str_or_blob sta.apinfo
D (440) nvs: nvs_get sta.scan_method 1
D (442) nvs: nvs_get sta.sort_method 1
D (446) nvs: nvs_get sta.minrssi 1
D (449) nvs: nvs_get sta.minauth 1
D (453) nvs: nvs_get_str_or_blob ap.ssid
D (457) nvs: nvs_get_str_or_blob ap.mac
D (461) nvs: nvs_get_str_or_blob ap.passwd
D (465) nvs: nvs_get_str_or_blob ap.pmk
D (469) nvs: nvs_get ap.chan 1
D (472) nvs: nvs_get ap.authmode 1
D (475) nvs: nvs_get ap.hidden 1
D (478) nvs: nvs_get ap.max.conn 1
D (482) nvs: nvs_get bcn.interval 2
D (486) nvs: nvs_get ap.phym 1
D (489) nvs: nvs_get ap.phybw 1
D (492) nvs: nvs_get ap.sndchan 1
D (495) nvs: nvs_get lorate 1
D (499) nvs: nvs_set_blob sta.mac 6
D (504) nvs: nvs_set_blob ap.mac 6
I (507) wifi: Init dynamic tx buffer num: 32
I (509) wifi: Init data frame dynamic rx buffer num: 32
I (514) wifi: Init management frame dynamic rx buffer num: 32
I (520) wifi: Init management short buffer num: 32
I (524) wifi: Init static rx buffer size: 1600
I (528) wifi: Init static rx buffer num: 10
I (532) wifi: Init dynamic rx buffer num: 32
D (536) nvs: nvs_get_str_or_blob ssid
D (540) nvs: nvs_get ssid 4
D (543) nvs: nvs_set_blob ap.ssid 36
D (548) nvs: nvs_set_blob ap.passwd 65
D (552) nvs: nvs_set ap.authmode 1 0
D (554) nvs: nvs_set ap.chan 1 1
D (558) nvs: nvs_set ap.hidden 1 0
D (561) nvs: nvs_set ap.max.conn 1 1
D (565) nvs: nvs_set bcn.interval 2 16381
D (569) RTC_MODULE: Wi-Fi takes adc2 lock.
D (573) phy_init: loading PHY init data from application binary
D (579) nvs: nvs_open_from_partition phy 0
D (583) nvs: nvs_get cal_version 4
D (586) nvs: nvs_get_str_or_blob cal_mac
D (591) nvs: nvs_get_str_or_blob cal_data
D (600) nvs: nvs_close 4
I (674) phy: phy_version: 4008, 544f89f, Jan 24 2019, 14:54:06, 0, 0
I (676) wifi: mode : softAP (84:0d:8e:e6:6d:a5)
I (677) wifi: Total power save buffer number: 16
I (679) wifi: Init max length of beacon: 752/752
I (684) wifi: Init max length of beacon: 752/752
D (688) event: SYSTEM_EVENT_AP_START
I (691) TRS-IO: wifi_init_ap finished.SSID:TRS-IO
D (693) tcpip_adapter: dhcp server start:(ip: 192.168.4.1, mask: 255.255.255.0, gw: 192.168.4.1)
I (697) gpio: GPIO[12]| InputEn: 1| OutputEn: 0| OpenDrain: 0| Pullup: 0| Pulldown: 0| Intr:0
I (715) gpio: GPIO[13]| InputEn: 1| OutputEn: 0| OpenDrain: 0| Pullup: 0| Pulldown: 0| Intr:0
I (724) gpio: GPIO[14]| InputEn: 1| OutputEn: 0| OpenDrain: 0| Pullup: 0| Pulldown: 0| Intr:0
I (733) gpio: GPIO[15]| InputEn: 1| OutputEn: 0| OpenDrain: 0| Pullup: 0| Pulldown: 0| Intr:0
I (742) gpio: GPIO[16]| InputEn: 1| OutputEn: 0| OpenDrain: 0| Pullup: 0| Pulldown: 0| Intr:0
I (752) gpio: GPIO[17]| InputEn: 1| OutputEn: 0| OpenDrain: 0| Pullup: 0| Pulldown: 0| Intr:0
I (761) gpio: GPIO[18]| InputEn: 1| OutputEn: 0| OpenDrain: 0| Pullup: 0| Pulldown: 0| Intr:0
I (770) gpio: GPIO[19]| InputEn: 1| OutputEn: 0| OpenDrain: 0| Pullup: 0| Pulldown: 0| Intr:0
I (780) gpio: GPIO[32]| InputEn: 1| OutputEn: 0| OpenDrain: 0| Pullup: 0| Pulldown: 0| Intr:0
I (789) gpio: GPIO[33]| InputEn: 1| OutputEn: 0| OpenDrain: 0| Pullup: 0| Pulldown: 0| Intr:0
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
apuder, 2020-01-05:
It seems the HTTP task is not running which is why you cannot connect. But you shouldn't get those watchdog timers either. What is the precise ESP32 model you are using?

iceblu3710, 2020-01-05:
The only one easily available was Digikey 1965-1003-ND. ESP32-WROOM-32D

iceblu3710, 2020-01-17:
Any ideas? The 32 and 32D are the same chip just a different die revision and layout under the can.

apuder, 2020-01-17:
This is the ESP32 version I am using:
https://www.amazon.com/gp/product/B0718T232Z/ref=ppx_yo_dt_b_search_asin_title?ie=UTF8&psc=1

I know that @jaquinn also had some issues with other ESP32 flavors. If possible, could you try the version I am using?

jaquinn, 2020-02-19:
There is a pending pull request which updates the build documentation to confirm the supported ESP32 modules and the orientation on the board.

Interestingly, I had similar issues with the Task Watchdog and it was due to omitting to solder of pin 1 on both the 74LVC245.  Have a close look at your board to be sure the solder joints are all OK.

vodkaflip, 2020-12-15:
Bumping this older issue: on the M1 version, I get the 48k expansion (holding down break). So that part works... The ESP32 however connects to the wifi (SSID and password hardcoded), starts Mongoose but then along the way, wifi disconnects (reason 8, assoc leave) and I get a SW_CPU_RESET) and the whole cycle starts again.

`I (2347) TRS-IO: Starting Mongoose
D (2347) nvs: nvs_get_str_or_blob tz
D (2349) nvs: nvs_get tz 4
D (2356) nvs: nvs_get_str_or_blob ssid
D (2357) nvs: nvs_get_str_or_blob ssid
D (2359) nvs: nvs_get_str_or_blob passwd
D (2373) nvs: nvs_get_str_or_blob passwd
D (2374) nvs: nvs_get_str_or_blob tz
D (2374) nvs: nvs_get tz 4
D (2375) nvs: nvs_get_str_or_blob smb_url
D (2378) nvs: nvs_get_str_or_blob smb_url
D (2382) nvs: nvs_get_str_or_blob smb_user
D (2386) nvs: nvs_get_str_or_blob smb_user
D (2390) nvs: nvs_get_str_or_blob smb_passwd
D (2394) nvs: nvs_get_str_or_blob smb_passwd
D (2557) phy_init: wifi mac time delta: 6616
D (2779) phy_init: wifi mac time delta: 31883
D (2842) phy_init: wifi mac time delta: 4254
D (2945) phy_init: wifi mac time delta: 30471
D (3047) phy_init: wifi mac time delta: 86897
D (3150) phy_init: wifi mac time delta: 88863
D (3152) nvs: nvs_erase_all

I (3160) wifi:state: run -> init (0)
I (3161) wifi:pm stop, total sleep time: 602049 us / 1559244 us

I (3162) wifi:new:<2,0>, old:<2,0>, ap:<255,255>, sta:<2,0>, prof:1
D (3165) event: SYSTEM_EVENT_STA_DISCONNECTED, ssid:SECTOR7g, ssid_len:8, bssid:04:d9:f5:b3:d9:e0, reason:8,wifi reason: assoc leave
D (3178) tcpip_adapter: if0 start ip lost tmr: enter
D (3182) tcpip_adapter: if0 start ip lost tmr: interval=120
D (3188) event: SYSTEM_EVENT_STA_STOP
I (3202) wifi:flush txq
I (3202) wifi:stop sw txq
D (3203) phy_init: wifi mac time delta: 64
I (3204) wifi:lmac stop hw txq
D (3205) RTC_MODULE: Wi-Fi returns adc2 lock.
ets Jun  8 2016 00:22:57

rst:0xc (SW_CPU_RESET),boot:0x13 (SPI_FAST_FLASH_BOOT)`

I had some trouble compiling the source until I downgraded ESP_IDF to version 3.3.4. I am using SDCC 4.0 - could that be the issue (I have to change one line as sdcclib no longer exists)

apuder, 2021-12-25:
I'm closing this issue. TRS-IO now requires ESP-IDF 4.2.2. If you have issues with the latest version, please re-open this issue.

Closed 2021-12-25.

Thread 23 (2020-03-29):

Autoboot disks don't work, only autoboot eproms.

ngtwolf, 2020-03-29:
This is less of an issue and more of a feature request.  Unlike the FreHD, the TRS-IO doesn't auto booting from the autoboot disks like a FreHD does, it only appears to work with an autoboot eprom.  Would be nice to allow it to work with autoboot disks as well, for those who don't want to (or can't easily) update replace the rom in their trs-80.

apuder, 2020-04-17:
I am not sure how the autoboot disk works. I would assume that it uses the same bootstrap mechanism as the ROM patch. That does not seem to be the case. Do you have the source to the autoboot disk? Unfortunately I do not have floppy drives so I cannot test it myself but I'd like to check the source.

kwadsten, 2020-04-17:
Not sure if this is relevant or not, but this BASIC program is supposed to be the equivalent of the FreHD autoboot ROM...

FreHD BASIC Loader

10 POKE 16912,56:OUT 236,56
20 OUT 197,3:REM 1=M1, 3=M3, 4=M4/M4A, 5=M4P
30 IF INP(196)<>254 STOP
40 FOR I=0 TO 255:POKE 20480+I,INP(196):NEXT

SYSTEM
/20480

apuder, 2020-04-17:
Actually, you can add those lines here:
`50 POKE16526,0
60 POKE16527,80
70 PRINT USR(0)`
This way you do not have to use the SYSTEM command. You should be able to turn this into an autoboot disk. @ngtwolf can you please verify?

ngtwolf, 2020-04-19:
So, a few things.  Right now I have an autoboot rom in there (had to break down and do that because originally i didn't know if my trs-io build was bad or just that the frehd autoboot disks didn't work with the trs-io... and after i put the rom in, i was able to confirm it was the autoboot disks that didn't work) so i'm not sure how good my test is, but I did get it working it seems.  A few things though:

1) line 30 should be 'THEN STOP".

2) The first set of code seems to work, if I do the system and the /20480 command... However the additional code (50/60/70) either doesn't do anything or gets an illegal function call at 70.

3) It works on LDOS 5.3.x, but doesn't work on lsdos 6.x (similar to rsclient).  I think that's a moot point though because if It can be made to work on a 5.3 disk, that would work for boot purposes anyway and would support both model 3/4.

4)  I also noticed that on my Model 4 GA, that line 30 works with either 3 or 4.. so in theory a LDOS 5.x boot disk could be made to support either Model 3 or 4 with the same program.  Of course, just need to figure out how to do this with some autoboot disk rather than the basic/system command.

Anyway, It would be a pain to confirm this works with the original rom since i'd have to open it back up, but I guess I could do that if we could have a working bootable disk to try that would boot to the frehd.

Thanks!

apuder, 2020-04-19:
Couple of quick questions: did you use a M3 or M4 for your tests? Also, where did you get the autoboot floppy from? Do you happen to have the source of whatever is on that autoboot disk?

ngtwolf, 2020-04-19:
Mentioned in my comment above, but it's a Model 4 Gate Array (which is why i originally couldn't do a boot rom since it's a pain to do on the gate array since it needs a special board that I had to have made which took a while and was hoping i could get by without doing that at least to make sure everything worked).

The autoboot disks I thought I got on ian mavrics site at one point but I can't ever find anything there, so heres the creators site (FreHD Boot Floppies file):

https://desertsagesolutions.com/sw/

apuder, 2021-12-25:
Fixed in commit 37639e0c01467c2f105af56a36e599fbf7b4413e.

Closed 2021-12-25.

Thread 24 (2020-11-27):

Feature Request #1 - Serial Port / Modem Emulation

Howlinmoon, 2020-11-27:
Hi,
I couldn't figure out how to contact you directly - so I'm opening an issue to ask these questions.
I watched your presentation on Trash Talk Live #7 and it appears that all of the address lines are available to the ESP32, so I was hoping to lodge a feature request issue:

If the TRS-IO could emulate an RS-232 port/Modem (Ports E8-EB) and a basic AT command set, then this would be a true one stop shopping experience for programs that use the serial port.

There are a wealth of retro-BBSs reachable via telnet, and there is a market for items such as the WiFi232 type wireless modems.   The TRS-IO should be able to easily perform the same function as those devices.
This would allow the native TRS-80 Comm programs to work with the TRS-IO - and any multiplayer games such as the famous Adventure International game: COMMBAT.  I am sure there are other games that utilizes the serial port, this is just my favorite :-)

Serial Port / Modem Emulation would also allow downloading of files via the comm programs from remote systems.
As far the TRS-80 and the comm programs are concerned - they would be talking to a real UART connected to a real Modem.

apuder, 2020-11-27:
That should be possible for the M1 version of TRS-IO. The M3 version would need some PCB changes. I'll add it to my (long) TODO list. :)

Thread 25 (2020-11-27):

Feature Request #2 - Floppy Drive emulation

Howlinmoon, 2020-11-27:
Looking at the FreHD, it appears to only emulate hard disk images, but not floppy drives.
There are a wealth of floppy disk images (protected or non-standard booting) in the DMK format that are not easily transferred to a hard disk image.

Since it appears that all of the required port and address lines are available to the TRS-IO, this feature request is to add floppy drive emulation.
Surely the ESP32 has enough computing power to handle reading and writing to emulated floppy disk images.
This would be similar in functionality to the popular Gotek type floppy disk emulators - but built nicely into one package.

Mounting the floppy disk images could be handled in the same fashion as the hard disk images for the FreHD - out of band via either the on screen configuration - or even via the web interface.

apuder, 2020-11-27:
That is a nice idea but most likely not possible. I/O cards such as TRS-IO or FreHD assert the WAIT* pin to give themselves enough time to finish a request. This works well for in/out operations on the I/O port; but it does NOT work for memory mapped I/O. This is a peculiarity of the Z80 CPU: a WAIT* signal can be generated for memory read requests, but NOT write requests. If you look at the timing diagrams for the  Z80 memory access you can see the reason why. Bottom line: An I/O card cannot intercept memory mapped write access. That is what would be needed to emulate floppy disks, so I don't see a way to make that happen. Quick note on the auto-boot feature of TRS-IO for the M1: you may wonder why that works (since the auto boot is also floppy based). I checked the ROM code that the M1 uses to load the boot loader and just by intercepting read requests, I can "fly blind" and return that the ROM expects. But if you begin to issue other FDC commands, my autoboot code will no longer work.

Howlinmoon, 2021-02-19:
As per TrashTalk Live #11 - I see you have changed your mind...
I knew it had to be possible - since the original expansion interface was working and it has only the same edge connector signals available to it as TRS-IO does.
I look forward to the board revision that will enable intercepting the memory writes.

Closed 2020-11-27.

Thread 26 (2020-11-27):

Feature Request #3 - Printer Emulation

Howlinmoon, 2020-11-27:
To finish out a complete package, if my other feature requests were implemented, the only feature lacking from the complete expansion solution is a printer port emulation.

Arguably, the majority of printing performed back in the day was simple text printouts from within programs and LLISTings of the current BASIC program.

This would just require a buffer to capture the text sent to the emulated printer port - which could then be retrieved and downloaded via the web interface as a simple text file.

That would suffice for probably 90% of the use cases, to handle the other 10% (just random percentages I'm making up) going above and beyond would be to emulate something like the Epson MX80's graphics codes and other special characters - and instead of creating a simple text dump - emulate how the printer would output the data by creating a downloadable PDF file from the web interface.

I personally, would be happy with a plain text capture / dump mechanism - but if you are feeling extra motivated... :-)

apuder, 2020-11-27:
How does the M1/MIII access the printer? Via the I/O port or memory mapped access? If the latter, it won't be possible (see my comment for the FDC support)

apuder, 2021-12-25:
The latest version does support printer emulation. Visit trs-io.local/printer then use LPRINT or LLIST. The web interface is barebones. PRs welcome. :)

Closed 2021-12-25.

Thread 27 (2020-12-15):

Model I long button press triggered

vodkaflip, 2020-12-15:
On the model I version, is_button_long_press seems to be continuously triggered. This results in the ESP32 erasing the stored credentials and resetting continuously. If I comment out that piece of code (in /src/esp/main/io.cpp), the TRS-IO works as it should.

apuder, 2020-12-15:
I have noticed that as well. There seems to be an issue with the latest stable version of the ESP-IDF v3 branch. Please use v3.2.2 of the ESP-IDF as well as the toolchain. That works for me without any modification of io.cpp.

Closed 2020-12-15.

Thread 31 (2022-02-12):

BUILD INSTRUCTIONS: Debian 11

AdamM-AU, 2022-02-12:
Hi all here is my build script/instructions for debian 11

#TRS-IO - Build Instructions
#OS: Debian 11

#Install Prerequisites:
#Packages for Espressif
sudo apt-get install git wget flex bison gperf python3 python3-pip python3-setuptools cmake ninja-build ccache libffi-dev libssl-dev dfu-util libusb-1.0-0

#Packages for TRS-IO
sudo apt-get install z80asm sdcc sdcc-libraries

# Some Fixes for linking libraries thats needed by TRS-IO
sudo mkdir -p /lib/z80/
sudo ln -s /usr/share/sdcc/lib/z80/z80.lib /lib/z80/z80.lib

#Python3 as default:
sudo apt-get install python3 python3-pip python3-setuptools
sudo ln -s /usr/bin/python3 /usr/bin/python

#ESP-IDF (Blanket Install Everything):
mkdir -p ~/esp
cd ~/esp
git clone -b v4.2 --recursive https://github.com/espressif/esp-idf.git
cd ~/esp/esp-idf
export IDF_GITHUB_ASSETS="dl.espressif.com/github_assets"
./install.sh
. $HOME/esp/esp-idf/export.sh

#CHECK OUT TRS-IO
cd ~/esp
git clone --recursive https://github.com/apuder/TRS-IO.git
cd TRS-IO
make all

# Completed Build Path

aihk, 2022-04-29:
Failed to make successfully

[996/1037] Building CXX object esp-idf/main/CMakeFiles/__idf_main.dir/io-xray.cpp.obj
FAILED: esp-idf/main/CMakeFiles/__idf_main.dir/io-xray.cpp.obj
/home/aihk/.espressif/tools/xtensa-esp32-elf/esp-2020r3-8.4.0/xtensa-esp32-elf/bin/xtensa-esp32-elf-g++ -DMBEDTLS_CONFIG_FILE=\"mbedtls/esp_config.h\" -Iconfig -I../main/include -I../../../../components/newlib/platform_include -I../../../../components/freertos/include -I../../../../components/freertos/xtensa/include -I../../../../components/heap/include -I../../../../components/log/include -I../../../../components/lwip/include/apps -I../../../../components/lwip/include/apps/sntp -I../../../../components/lwip/lwip/src/include -I../../../../components/lwip/port/esp32/include -I../../../../components/lwip/port/esp32/include/arch -I../../../../components/soc/src/esp32/. -I../../../../components/soc/src/esp32/include -I../../../../components/soc/include -I../../../../components/esp_rom/include -I../../../../components/esp_common/include -I../../../../components/esp_system/include -I../../../../components/xtensa/include -I../../../../components/xtensa/esp32/include -I../../../../components/esp32/include -I../../../../components/driver/include -I../../../../components/driver/esp32/include -I../../../../components/esp_ringbuf/include -I../../../../components/efuse/include -I../../../../components/efuse/esp32/include -I../../../../components/espcoredump/include -I../../../../components/esp_timer/include -I../../../../components/esp_ipc/include -I../../../../components/soc/soc/esp32/include -I../../../../components/soc/soc/esp32/../include -I../../../../components/soc/soc/esp32/private_include -I../../../../components/vfs/include -I../../../../components/esp_wifi/include -I../../../../components/esp_wifi/esp32/include -I../../../../components/esp_event/include -I../../../../components/esp_netif/include -I../../../../components/esp_eth/include -I../../../../components/tcpip_adapter/include -I../../../../components/app_trace/include -I../../../../components/app_update/include -I../../../../components/spi_flash/include -I../../../../components/bootloader_support/include -I../../../../components/nvs_flash/include -I../../../../components/mbedtls/port/include -I../../../../components/mbedtls/mbedtls/include -I../../../../components/mbedtls/esp_crt_bundle/include -I../../../../components/sdmmc/include -I../../../../components/fatfs/diskio -I../../../../components/fatfs/vfs -I../../../../components/fatfs/src -I../../../../components/wear_levelling/include -I../components/frehd/include -I../components/trs-fs/include -I../components/libsmb2/lib -I../components/libsmb2/include -I../components/libsmb2/include/smb2 -I../components/libsmb2/include/esp -I../../../../components/mdns/include -I../../../../components/console -I../components/retrostore/include -I../components/trs-io/include -I../components/tcpip/include -mlongcalls -Wno-frame-address -ffunction-sections -fdata-sections -fstrict-volatile-bitfields -Wall -Werror=all -Wno-error=unused-function -Wno-error=unused-but-set-variable -Wno-error=unused-variable -Wno-error=deprecated-declarations -Wextra -Wno-unused-parameter -Wno-sign-compare -ggdb -Og -std=gnu++11 -fno-exceptions -fno-rtti -D_GNU_SOURCE -DIDF_VER=\"v4.2\" -DESP_PLATFORM -MD -MT esp-idf/main/CMakeFiles/__idf_main.dir/io-xray.cpp.obj -MF esp-idf/main/CMakeFiles/__idf_main.dir/io-xray.cpp.obj.d -o esp-idf/main/CMakeFiles/__idf_main.dir/io-xray.cpp.obj -c ../main/io-xray.cpp
In file included from ../components/trs-io/include/mongoose.h:120,
                 from ../components/trs-io/include/web_debugger.h:3,
                 from ../main/io-xray.cpp:21:
../../../../components/lwip/port/esp32/include/netdb.h:36:5: error: conflicting declaration of 'int getnameinfo(const sockaddr*, socklen_t, char*, socklen_t, char*, socklen_t, int)' with 'C' linkage
 int getnameinfo(const struct sockaddr *addr, socklen_t addrlen,
     ^~~~~~~~~~~
In file included from ../components/tcpip/include/tcpip.h:8,
                 from ../main/io-xray.cpp:13:
../../../../components/lwip/port/esp32/include/netdb.h:36:5: note: previous declaration with 'C++' linkage
 int getnameinfo(const struct sockaddr *addr, socklen_t addrlen,
     ^~~~~~~~~~~

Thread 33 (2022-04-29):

build error

aihk, 2022-04-29:
ESP32 Version  4.2.2
error：

esptool.py v3.1-dev
Merged 1 ELF section
Generated /home/aihk/esp/esp-idf/TRS-IO/src/esp/build/bootloader/bootloader.bin
[618/1040] Generating x509_crt_bundle
/home/aihk/.espressif/python_env/idf4.2_py3.9_env/lib/python3.9/site-packages/cryptography/x509/base.py:514: CryptographyDeprecationWarning: Parsed a negative serial number, which is disallowed by RFC 5280.
  return rust_x509.load_pem_x509_certificate(data)
[935/1040] Building C object esp-idf/libsmb2/CMakeFiles/__idf_libsmb2.dir/lib/dcerpc.c.obj
../components/libsmb2/lib/dcerpc.c:85:1: warning: missing initializer for field 'vers_minor' of 'p_syntax_id_t' {aka 'struct p_syntax_id'} [-Wmissing-field-initializers]
 };
 ^
In file included from ../components/libsmb2/lib/dcerpc.c:61:
../components/libsmb2/include/smb2/libsmb2-dcerpc.h:58:18: note: 'vers_minor' declared here
         uint16_t vers_minor;
                  ^~~~~~~~~~
../components/libsmb2/lib/dcerpc.c:89:1: warning: missing initializer for field 'vers_minor' of 'p_syntax_id_t' {aka 'struct p_syntax_id'} [-Wmissing-field-initializers]
 };
 ^
In file included from ../components/libsmb2/lib/dcerpc.c:61:
../components/libsmb2/include/smb2/libsmb2-dcerpc.h:58:18: note: 'vers_minor' declared here
         uint16_t vers_minor;
                  ^~~~~~~~~~
[942/1040] Building C object esp-idf/libsmb2/CMakeFiles/__idf_libsmb2.dir/lib/init.c.obj
../components/libsmb2/lib/init.c: In function 'smb2_init_context':
../components/libsmb2/lib/init.c:275:20: warning: unused variable 'ctr' [-Wunused-variable]
         static int ctr;
                    ^~~
../components/libsmb2/lib/init.c: In function 'smb2_set_password_from_file':
../components/libsmb2/lib/init.c:479:54: warning: this statement may fall through [-Wimplicit-fallthrough=]
                                 buf[strlen(buf) - 1] = 0;
                                 ~~~~~~~~~~~~~~~~~~~~~^~~
../components/libsmb2/lib/init.c:480:25: note: here
                         default:
                         ^~~~~~~
At top level:
../components/libsmb2/lib/init.c:275:20: warning: 'ctr' defined but not used [-Wunused-variable]
         static int ctr;
                    ^~~

[998/1040] Building CXX object esp-idf/main/CMakeFiles/__idf_main.dir/spi-xray.cpp.obj
In file included from ../main/spi-xray.cpp:8:
../../../../components/esp_event/include/esp_event_loop.h:2:2: warning: #warning "esp_event_loop.h is deprecated, please include esp_event.h instead" [-Wcpp]
 #warning "esp_event_loop.h is deprecated, please include esp_event.h instead"
  ^~~~~~~
../main/spi-xray.cpp: In function 'void init_spi()':
../main/spi-xray.cpp:428:3: warning: missing initializer for member 'spi_bus_config_t::flags' [-Wmissing-field-initializers]
   };
   ^
../main/spi-xray.cpp:428:3: warning: missing initializer for member 'spi_bus_config_t::intr_flags' [-Wmissing-field-initializers]
../main/spi-xray.cpp: At global scope:
../main/spi-xray.cpp:345:16: warning: 'uint8_t readDigiPot(uint8_t)' defined but not used [-Wunused-function]
 static uint8_t readDigiPot(uint8_t pot)
                ^~~~~~~~~~~
[1018/1040] Building CXX object esp-idf/trs-io/CMakeFiles/__idf_trs-io.dir/web_debugger.cpp.obj
../components/trs-io/web_debugger.cpp:436:13: warning: 'void handleDynamicUpdate()' defined but not used [-Wunused-function]
 static void handleDynamicUpdate() {
             ^~~~~~~~~~~~~~~~~~~
../components/trs-io/web_debugger.cpp:36:25: warning: 'next_async_action' defined but not used [-Wunused-variable]
 static TRX_CONTROL_TYPE next_async_action = TRX_CONTROL_TYPE_NOOP;
                         ^~~~~~~~~~~~~~~~~
../components/trs-io/web_debugger.cpp:22:12: warning: 'emulation_is_halting' defined but not used [-Wunused-variable]
 static int emulation_is_halting = false;
            ^~~~~~~~~~~~~~~~~~~~
[1019/1040] Building CXX object esp-idf/trs-io/CMakeFiles/__idf_trs-io.dir/wifi.cpp.obj
../components/trs-io/wifi.cpp:86:19: warning: invalid suffix on literal; C++11 requires a space between literal and string macro [-Wliteral-suffix]
     ESP_LOGI(TAG, "Station "MACSTR" join, AID=%d", MAC2STR(event->mac), event->aid);
                   ^
../components/trs-io/wifi.cpp:90:19: warning: invalid suffix on literal; C++11 requires a space between literal and string macro [-Wliteral-suffix]
     ESP_LOGI(TAG, "Station "MACSTR" leave, AID=%d", MAC2STR(event->mac), event->aid);
                   ^
../components/trs-io/wifi.cpp: In function 'bool mongoose_handle_config(mg_http_message*, char**, const char**)':
../components/trs-io/wifi.cpp:178:15: warning: ISO C++ forbids converting a string constant to 'char*' [-Wwrite-strings]   *response = "";
               ^~
../components/trs-io/wifi.cpp: In function 'void wifi_init_ap()':
../components/trs-io/wifi.cpp:398:3: warning: missing initializer for member 'wifi_ap_config_t::password' [-Wmissing-field-initializers]
   };
   ^

[1035/1040] Building CXX object esp-idf/retrostore/CMakeFiles/__idf_retrostore.dir/backend.cpp.obj
../components/retrostore/backend.cpp: In function 'char* get_app_title(int)':
../components/retrostore/backend.cpp:276:12: warning: ISO C++ forbids converting a string constant to 'char*' [-Wwrite-strings]
     return "";
            ^~
../components/retrostore/backend.cpp: In function 'char* get_app_details(int)':
../components/retrostore/backend.cpp:285:12: warning: ISO C++ forbids converting a string constant to 'char*' [-Wwrite-strings]
     return "";
            ^~
../components/retrostore/backend.cpp:288:12: warning: ISO C++ forbids converting a string constant to 'char*' [-Wwrite-strings]
     return "";
            ^~
[1039/1040] Linking CXX executable trs-io.elf
FAILED: trs-io.elf

/home/aihk/.espressif/tools/xtensa-esp32-elf/esp-2020r3-8.4.0/xtensa-esp32-elf/bin/../lib/gcc/xtensa-esp32-elf/8.4.0/../../../../xtensa-esp32-elf/bin/ld: esp-idf/wpa_supplicant/libwpa_supplicant.a(md5-internal.c.obj): in function `MD5Init':/home/aihk/esp/esp-idf/components/wpa_supplicant/src/crypto/md5-internal.c:93: multiple definition of `MD5Init'; esp-idf/libsmb2/lib..a(md5.c.obj):/home/aihk/esp/esp-idf/TRS-IO/src/esp/build/../components/libsmb2/lib/md5.c:58: first defined here
/home/aihk/.espressif/tools/xtensa-esp32-elf/esp-2020r3-8.4.0/xtensa-esp32-elf/bin/../lib/gcc/xtensa-esp32-elf/8.4.0/../../../../xtensa-esp32-elf/bin/ld: esp-idf/wpa_supplicant/libwpa_supplicant.a(md5-internal.c.obj): in function `MD5Update':
/home/aihk/esp/esp-idf/components/wpa_supplicant/src/crypto/md5-internal.c:109: multiple definition of `MD5Update'; esp-idf/libsmb2/lib..a(md5.c.obj):/home/aihk/esp/esp-idf/TRS-IO/src/esp/build/../components/libsmb2/lib/md5.c:74: first defined here
/home/aihk/.espressif/tools/xtensa-esp32-elf/esp-2020r3-8.4.0/xtensa-esp32-elf/bin/../lib/gcc/xtensa-esp32-elf/8.4.0/../../../../xtensa-esp32-elf/bin/ld: esp-idf/wpa_supplicant/libwpa_supplicant.a(md5-internal.c.obj): in function `MD5Final':
/home/aihk/esp/esp-idf/components/wpa_supplicant/src/crypto/md5-internal.c:158: multiple definition of `MD5Final'; esp-idf/libsmb2/lib..a(md5.c.obj):/home/aihk/esp/esp-idf/TRS-IO/src/esp/build/../components/libsmb2/lib/md5.c:114: first defined here
collect2: error: ld returned 1 exit status
ninja: build stopped: subcommand failed.
ninja failed with exit code 1

----------------------------------------------------------------

I tried for two days and changed different versions, but I couldn't build successfully.

aihk, 2022-05-01:
Successful, shut down

Closed 2022-05-01.

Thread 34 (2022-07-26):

SD card not working

troffon, 2022-07-26:
The SD card status on the TRS-IO Configuration page shows up red, when I hover the mouse over it says "Failed to initialize SD card".
I've tried a couple of SD cards, both Class 4 formatted as FAT32.

Checked connections of SD card holder to PCB.

WiFi/SMB share works fine.

apuder, 2022-07-26:
Can you post the ESP'S log? (idf.py monitor)

troffon, 2022-07-28:
Unfortunately I'm not familiar with the idf tools.
Attached a log which I got by connecting Putty to ESP32 serial port, hope this will be of use.
Thanks
[ESP32_Putty.log](https://github.com/apuder/TRS-IO/files/9206992/ESP32_Putty.log)

troffon, 2022-07-28:
After seeing that the ESP log failed early on sdmmc_card_init, I decided to re-solder all the sd card contacts.
Now the sd card is functioning correctly.
Closing this issue.

Closed 2022-07-28.

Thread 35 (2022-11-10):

SD-Card slot - cannot find available part TFP09-2-12B - is there a cross?

dhlav, 2022-11-10:
Hello, I've forked this project and noticed the sd card slot is using a part that doesn't seem to be available easily. Is there a cross # for this before I modify the footprint and board?  This is the M1 v2 non-xray. Thanks! Dave.

apuder, 2022-11-10:
This is the part I am using: https://www.aliexpress.us/item/2251832720637377.html

Closed 2022-11-10.

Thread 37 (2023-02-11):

SDK version - Eclipse version - M1 non-xray w/sd Q

dhlav, 2023-02-11:
Hello, just wondering what SDK (expressif) version is currently being used and the same for eclipse for this project. I couldn't find any reference (I may have missed it).

I also just built my board using the m1 non-xray with sd card. Is that going to be still functional with the current master branch? I do see the pictures at root of repo have changed.

If I get this right, I can help document the process to regenerate/build.

Thanks! Dave.

dhlav, 2023-02-24:
I was able to rollback to a commit that works now. I used 4.4.2 for esp. Eclipse I didn't use. I'm assuming fpga going forward from now on.

apuder, 2023-02-26:
Sorry for the slow response. Looks like you figured out the issue yourself. The current master no longer works on the non-FPGA versions. Since you manage to get it to work, it would be nice if you could send a PR with the version number as the branch name. E.g., trs-io-m1-1-0 or something like that. Then you can cherry pick fixes from master. But we don't plan to put any more effort into the non-FPGA version, FYI. Please close this comment if you have no further question.

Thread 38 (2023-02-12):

Is model 1 non-xray still supported?

dhlav, 2023-02-12:
Looks like the lastest io and spi for model 1 now only support FPGA not the expander. Is this correct? Is there plans to put this back in?

I built the hardware for a model 1 without the fpga, so I hope there's a branch/commit I can rollback to.

Thanks! Dave.

dhlav, 2023-02-24:
I was able to rollback to a proper commit and now everything seems to work well. I'll merge changes in that are appropriate from main.

Closed 2023-02-24.

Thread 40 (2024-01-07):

Details on version history is incomplete.

FreddyKElmSt, 2024-01-07:
What does each version do differently?

There are nine versions of the Model III boards, which I am looking to build, as well as many variants of the Model 1 board, Can you please explain the differences?

What source codes work for which version of board?

Which board would you recommend, the 2.2b?  Or a different board?

Does the source code work for the most recent board (2.2b)?

apuder, 2024-01-07:
We keep older versions in separate directories. In general, you should use the latest version of the PCB. The firmware will work for that version.

Closed 2024-01-07.

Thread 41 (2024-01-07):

ESP idf.py will not compile with ESP-IDF 5.1

Nephrite-FM, 2024-01-07:
ESP idf.py will not compile with ESP-IDF 5.1.2, and I have noticed that previous issues you closed out, for earlier versions of the ESP32 code you suggested you need to make and compile the ESP binaries with an older version of the IDF, so for the latest version you have posted here, which version do you need?  3.2.2 again?

I am going to run this in a Debian VM and see if it actually works there at all, per:
https://github.com/apuder/TRS-IO/issues/31

EDIT:  Will now bring up menuconfig in 4.2 ESP-IDF once I downloaded all the missing git dependencies like libsmb, TRS-LIB, etc., because of how the code expects mdns to work...  But Now it won't build because of some problem with how it is creating the partition table:

FAILED: esp-idf/trs-io/CMakeFiles/spiffs_elFinder_bin
cmd.exe /C "cd /D C:\Users\Nephr\Desktop\TRS-IO-master\src\esp\build\esp-idf\trs-io && C:\Espressif4.2\tools\cmake\3.16.4\bin\cmake.exe -E echo "Failed to create SPIFFS image for partition 'elFinder'. " "Check project configuration if using the correct partition table file." && C:\Espressif4.2\tools\cmake\3.16.4\bin\cmake.exe -E remove C:/Users/Nephr/Desktop/TRS-IO-master/src/esp/build/esp-idf/trs-io/4auM1.cmake && C:\Espressif4.2\tools\cmake\3.16.4\bin\cmake.exe -E env "FAIL_MESSAGE=Failing the build (see errors on lines above)" C:/Espressif4.2/tools/cmake/3.16.4/bin/cmake.exe -P C:/Espressif4.2/frameworks/esp-idf-v4.2.5/tools/cmake/scripts/fail.cmake"
Failed to create SPIFFS image for partition 'elFinder'.  Check project configuration if using the correct partition table file.
CMake Error at C:/Espressif4.2/frameworks/esp-idf-v4.2.5/tools/cmake/scripts/fail.cmake:3 (message):
  Failing the build (see errors on lines above)

apuder, 2024-01-07:
Please use ESP-IDF 4.4.4.

Nephrite-FM, 2024-01-08:
That did the trick on Debian 11, but not completely.  ESP-IDF Compiles in Debian, however it still fails with this partition problem with the TRS-IO git clone:

[3/1232] cd /home/vboxuser/esp/TRS-IO/src/esp/bu...xuser/esp/esp-idf/tools/cmake/scripts/fail.cmake

FAILED: esp-idf/trs-io/CMakeFiles/spiffs_elFinder_bin

cd /home/vboxuser/esp/TRS-IO/src/esp/build/esp-idf/trs-io && /usr/bin/cmake -E echo "Failed to create SPIFFS image for partition 'elFinder'. " "Check project configuration if using the correct partition table file." && /usr/bin/cmake -E remove /home/vboxuser/esp/TRS-IO/src/esp/build/esp-idf/trs-io/GHGVx.cmake && /usr/bin/cmake -E env "FAIL_MESSAGE=Failing the build (see errors on lines above)" /usr/bin/cmake -P /home/vboxuser/esp/esp-idf/tools/cmake/scripts/fail.cmake

Failed to create SPIFFS image for partition 'elFinder'.  Check project configuration if using the correct partition table file.

CMake Error at /home/vboxuser/esp/esp-idf/tools/cmake/scripts/fail.cmake:3 (message):

  Failing the build (see errors on lines above)

[5/1232] cd /home/vboxuser/esp/TRS-IO/src/esp/bu...xuser/esp/esp-idf/tools/cmake/scripts/fail.cmake

FAILED: esp-idf/trs-io/CMakeFiles/spiffs_roms_bin

cd /home/vboxuser/esp/TRS-IO/src/esp/build/esp-idf/trs-io && /usr/bin/cmake -E echo "Failed to create SPIFFS image for partition 'roms'. " "Check project configuration if using the correct partition table file." && /usr/bin/cmake -E remove /home/vboxuser/esp/TRS-IO/src/esp/build/esp-idf/trs-io/9Qhpu.cmake && /usr/bin/cmake -E env "FAIL_MESSAGE=Failing the build (see errors on lines above)" /usr/bin/cmake -P /home/vboxuser/esp/esp-idf/tools/cmake/scripts/fail.cmake

Failed to create SPIFFS image for partition 'roms'.  Check project configuration if using the correct partition table file.

CMake Error at /home/vboxuser/esp/esp-idf/tools/cmake/scripts/fail.cmake:3 (message):

  Failing the build (see errors on lines above)

[7/1232] Generating ../../partition_table/partition-table.bin

Partition table binary generated. Contents:

*******************************************************************************
# ESP-IDF Partition Table
# Name, Type, SubType, Offset, Size, Flags
nvs,data,nvs,0x9000,24K,
phy_init,data,phy,0xf000,4K,
factory,app,factory,0x10000,1536K,
html,data,spiffs,0x190000,200K,
*******************************************************************************

[8/1232] Building C object esp-idf/mbedtls/mbedtls/library/CMakeFiles/mbedcrypto.dir/dhm.c.obj

ninja: build stopped: subcommand failed.

ninja failed with exit code 1

make[1]: *** [Makefile:9: all] Error 2

make[1]: Leaving directory '/home/vboxuser/esp/TRS-IO/src'

make: *** [Makefile:8: all] Error 1

Nephrite-FM, 2024-01-08:
Ok, it compiled all the way for me in ESP-IDF 4.4.6 for Windows.  Perhaps Debian didn't clean out ESP-IDF 4.2 fully, So I'll try recreating the Debian steps with 4.4.4 in a fresh Debian 11 VM.

I got to the point where it wants me to flash the ESP32 chip, so if I have to change settings around, I can go into the idf.py menuconfig and fix whatever might be broken.

apuder, 2024-01-08:
Make sure to do idf.py menuconfig and select the Model III.

Nephrite-FM, 2024-01-09:
> Make sure to do idf.py menuconfig and select the Model III.

Will do, thanks

Nephrite-FM, 2024-02-25:
This did nothing.  Although 4.4.6 appeared to flash the ESP32 Module, when the ESP32 is in the board and connected to the Model III, we do not get a white LED, nor do we get a SSID entitled "TRS-IO", so clearly the flashing didn't work or what was flashed to the ESP32 was not properly compiled.

Where are the instructions that walk users through compiling this, and pointing us to the right resources to compile this?

Nephrite-FM, 2024-02-25:
You should also be aware that there was no ESP-IDF 4.4.4 Release, nor can I get it to compile again.  The process keeps returning different errors every single time, terminating itself at random points through the compile process.

Try 1 - build fails at 3/1235 and 5/1235
Try 2 - build fails at 625/1222 and 627/1222
Try 3 - build fails at 2/595 and 4/595
and so on...

apuder, 2024-02-26:
Please try the last stable release of the v4.4 (which is 4.4.6)

Closed 2024-01-07.

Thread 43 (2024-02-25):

ESP32 Will not respond to flashed ELF, provide SSID or even turn the LED White

Nephrite-FM, 2024-02-25:
We have recently built your board, flashed the ESP32 and the Tang Nano.  Although 4.4.6 appeared to flash the the ESP32 Module over USB successfully, when the ESP32 is in the board and connected to the Model III, we do not get a white LED, nor do we get a SSID entitled "TRS-IO", so clearly the flashing didn't work or what was flashed to the ESP32 was not properly compiled.

You make a suggestion in an earlier issue that items in the src folder need to be built with MAKE.  What precisely needs to be compiled here?

Where are the instructions that walk users through compiling this, and pointing us to the right resources to compile this?

FreddyKElmSt, 2024-02-25:
I'm also having this same issue

apuder, 2024-02-26:
Please check the ESP logs (idf.py monitor). Did you also flash the 9K? The ESP tries to find the FPGA and will only continue with the boot process once it found the 9K. That would be my guess, but hopefully the logs will give a hint on what is going on.

Nephrite-FM, 2024-03-02:
it says SPI: FPGA Not Found, repeatedly.  I'll try reflashing the Tang Nano...

Is there some reason GOWIN says it is flashed when it isn't actually flashed?  How can we test the Nano is actually flashed?

Nephrite-FM, 2024-03-02:
Digging on the Web, the latest GOWIN has Problems with the TANG boards, I'll try flashing it with Education version 1.9.8.03 others recommend...

Nephrite-FM, 2024-03-02:
Ok, OpenFPGALoader, once I got it loaded with its missing dependencies in MSYS2, flashed the Tang NANO, and the ESP32 says it has found it...  Now, however it just flashes BLUE-GREEN-WHITE-OFF-WHITE at us, while still not broadcasting an SSID.

it gets this far:

I (1061) SPI: Found FPGA
I (1065) gpio: GPIO[4]| InputEn: 0| OutputEn: 1| OpenDrain: 0| Pullup: 0| Pulldown: 0| Intr:0
I (1074) gpio: GPIO[5]| InputEn: 0| OutputEn: 1| OpenDrain: 0| Pullup: 0| Pulldown: 0| Intr:0
I (1083) gpio: GPIO[32]| InputEn: 0| OutputEn: 1| OpenDrain: 0| Pullup: 0| Pulldown: 0| Intr:0

and then stops.

apuder, 2024-03-02:
Just to be sure, you did run `idf.py menuconfig` and selected the right TRS-IO model, right?

Nephrite-FM, 2024-03-02:
Correction - I Recompiled the ESP-32 with the Windows toolchain disabling the LED Test, and now it is flashing Cyan repeatedly, and broadcasting an SSID.  Apparently the RED LED line isn't connected right, I'll look into that later...

The only trouble now is that it is failing to read an SD Card (How do we need to format it?  FAT32 like the FreHD?), and on top of that, the basic snippets meant to retrieve the IP Address fail, even though we get a solid blue light for a few seconds (Still trying to trace down the GPIO Lines).

Yes, we did choose the Model III.

apuder, 2024-03-03:
So, it seems that the Wifi is up and running. Can you connect to the TRS-IO network with your laptop? Can you provide the credentials of your home network? Remember that the ESP can only connect to 2.4 GHz networks. As for the SD card; yes, regular FAT32 should do it. Note that the ESP does not detect insertion or ejection of the SD card. You have to reboot the ESP if you do that.

Nephrite-FM, 2024-03-03:
We have tried rebooting and even hard-powering and it still fails to recognize the SD Card.  We were able to connect it to the home WiFi, and what happens when it connects, GPIO32 lights up - Your board has GPIO32 of the ESP32 running to the Blue LED, and even your KICAD has that pin marked LED-Blue.

Another glitch - GPIO5 is not connected to the RED LED line as in your circuit or code, the way the pinout is, Pin 32 of the ESP32 is actually GPIO21.  I am trying to go through menuconfig to correct GPIO5 to be GPIO21.  GPIO4, as wired, does run to the green circuit (PIN 26).  We were sure to get the HiLetGo ESP32 module, but for some reason the pinout is wrong.  It is very likely that other GPIO Lines are also incorrect...

Nephrite-FM, 2024-03-03:
OK, I fixed GPIO5 to be GPIO21, and the LED Test is now faithfully flashing RED-BLUE-GREEN-WHITE-OFF-WHITE.

SO, Now, I will need to figure out from the circuit what GPIO Lines are supposed to be connected to the TANG NANO 9K - it can't be all wrong as the ESP32 is detecting the FPGA...

Nephrite-FM, 2024-03-03:
The trouble is, if the pinout is indeed incorrect, precisely which HiletGo module should we get?  Because I don't see in the configurator how we may set the I/O lines to the FPGA...

apuder, 2024-03-03:
The LED is connected to different pins for the M1 and M3. You are correct that you have to manually configure the correct GPIO pins in menuconfig. Actually, I removed that option in the latest version and it will automatically pick the right pins. Perhaps do a git pull. As for the SD card: it seems that SPI is working, so the one thing that might not be OK is the CS line for the SD card (the SD card has the same SCK, MISO and MOSI)

Nephrite-FM, 2024-03-03:
while trying to build it with the OTA enabled, even with the new git, we get this:
C:/ASS/trs-io/src/esp/main/ota.cpp:3:10: fatal error: storage.h: No such file or directory
 #include "storage.h"
          ^~~~~~~~~~~
compilation terminated.

so I leave it disabled - and we get a flag indicating FreHD, however the RetroStore and FreHD Functionality still do not work.

The IP Address Basic code does work, although it pulls the wrong IP address...  So I believe the next step for us is to see if we've burnt out one of the tranceiver/translator lines, or there might be a short somewhere - although I did tone-test it out, there is still something amiss - It reports its IP as 082.068.0.060 but the Modem says it is 192.168.1.171 - so, right off the bat we can tell that bit 1 is not getting through...

apuder, 2024-03-03:
Please do not select either OTA or RetroStore options. You wrote that "It reports its IP as 082.068.0.060". The ESP logs the IP address in decimal, without leading 0s. Where did you see this? Please check the ESP logs. In case you use Discord, we can move the discussion here: https://discord.gg/pJPHn8K5

Nephrite-FM, 2024-03-03:
We see 082.068.0.060 when running this on the TRS-80:

10 OUT 236,16
20 OUT31,0:OUT31,4
30 C=INP(31):IF C=0 THEN END
40 PRINT CHR$(C);
50 GOTO 30

Nephrite-FM, 2024-04-11:
Ok, turns out it was faulty wiring.  One of our Translator-Transceivers has 2 pins shorted, which would screw up te Data and Address buses.

airgunning off the chips and reseating them seems to have fixed a number of issues - except for some reason, unless an SD Card is inserted, Wi-Fi is present and a valid SMB share is defined, it will not initialize and Identify itself to the TRS-80.

We can use the latest Version of Gowin to Compile the nano9k VHDL, but I used MSYS2 + OpenFPGALoader to get it on the Tang nano.  The ESP-IDE 4.4.6 Toolchain for windows did work, and there were a few minor code tweaks to get it going enough to where FreHD and the RetroStore started Working by having it ignore the status of SMB - so looking forward to the next Git Release.

Closed 2024-04-11.

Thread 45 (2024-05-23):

BOM for TRS-IO Model 1 v1.4?

joshsucher, 2024-05-23:
Is there a BOM for the latest version of the TRS-IO for Model 1 board? thank you!

magore, 2025-01-01:
FYI - you can export a BOM in KiCAD as a CSV file - this has some useful information in it

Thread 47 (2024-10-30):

BOM for M3 v2.2b

StargeezerLabs, 2024-10-30:
Hello: I am trying to find a parts list/BOM for the M3 v2.2b.  While I can see component types in the schematic, I could use information about the size of the SMD components.  Any assistance is appreciated.

magore, 2025-01-01:
FYI - You can export a BOM in KiCAD that has some of these details

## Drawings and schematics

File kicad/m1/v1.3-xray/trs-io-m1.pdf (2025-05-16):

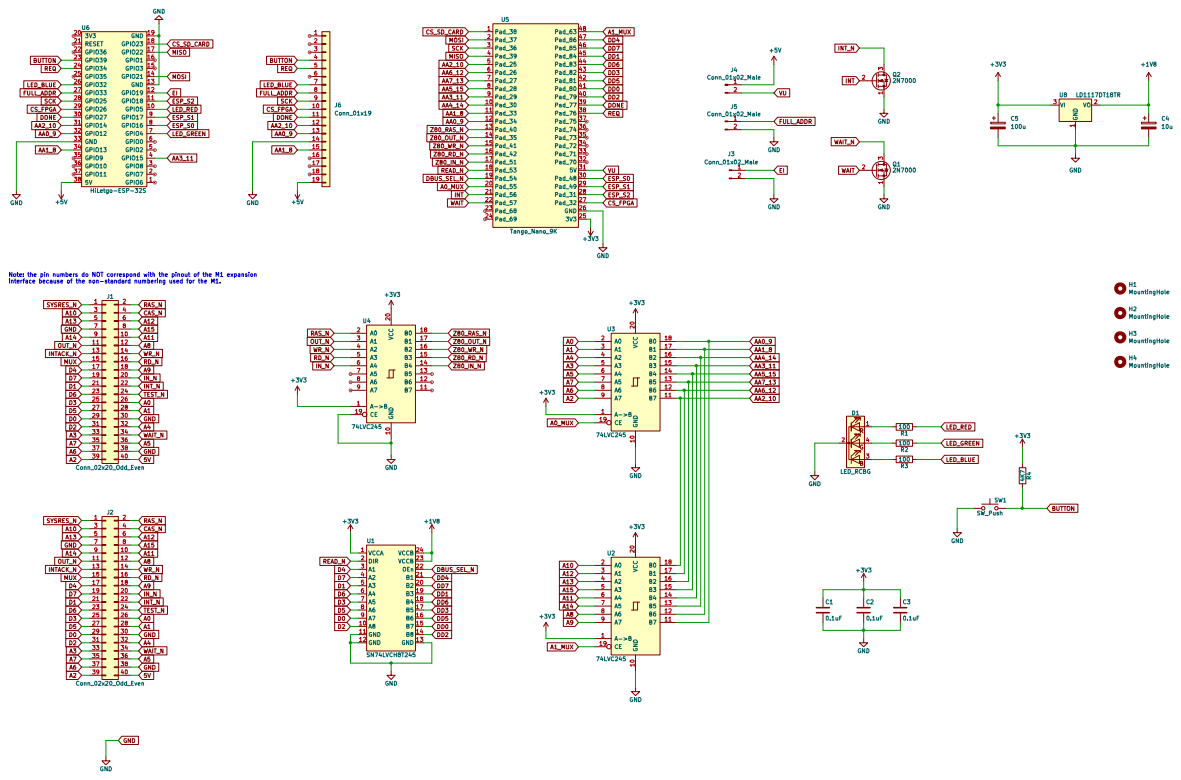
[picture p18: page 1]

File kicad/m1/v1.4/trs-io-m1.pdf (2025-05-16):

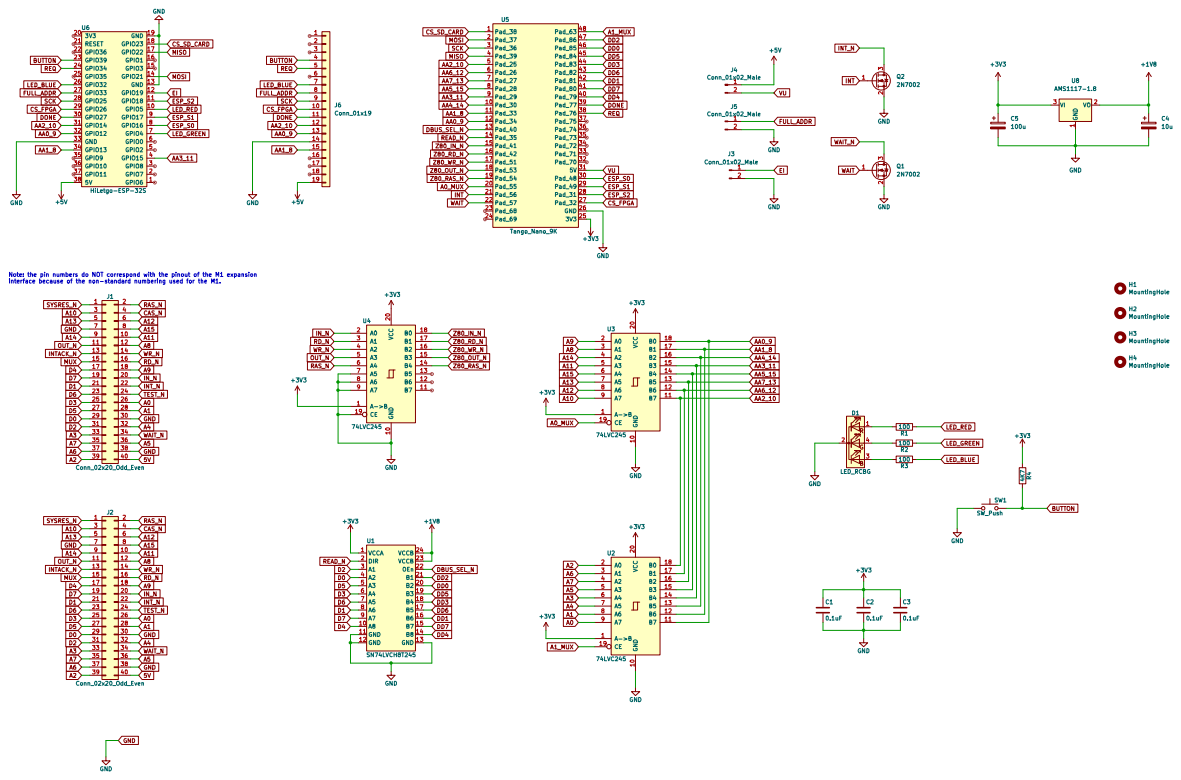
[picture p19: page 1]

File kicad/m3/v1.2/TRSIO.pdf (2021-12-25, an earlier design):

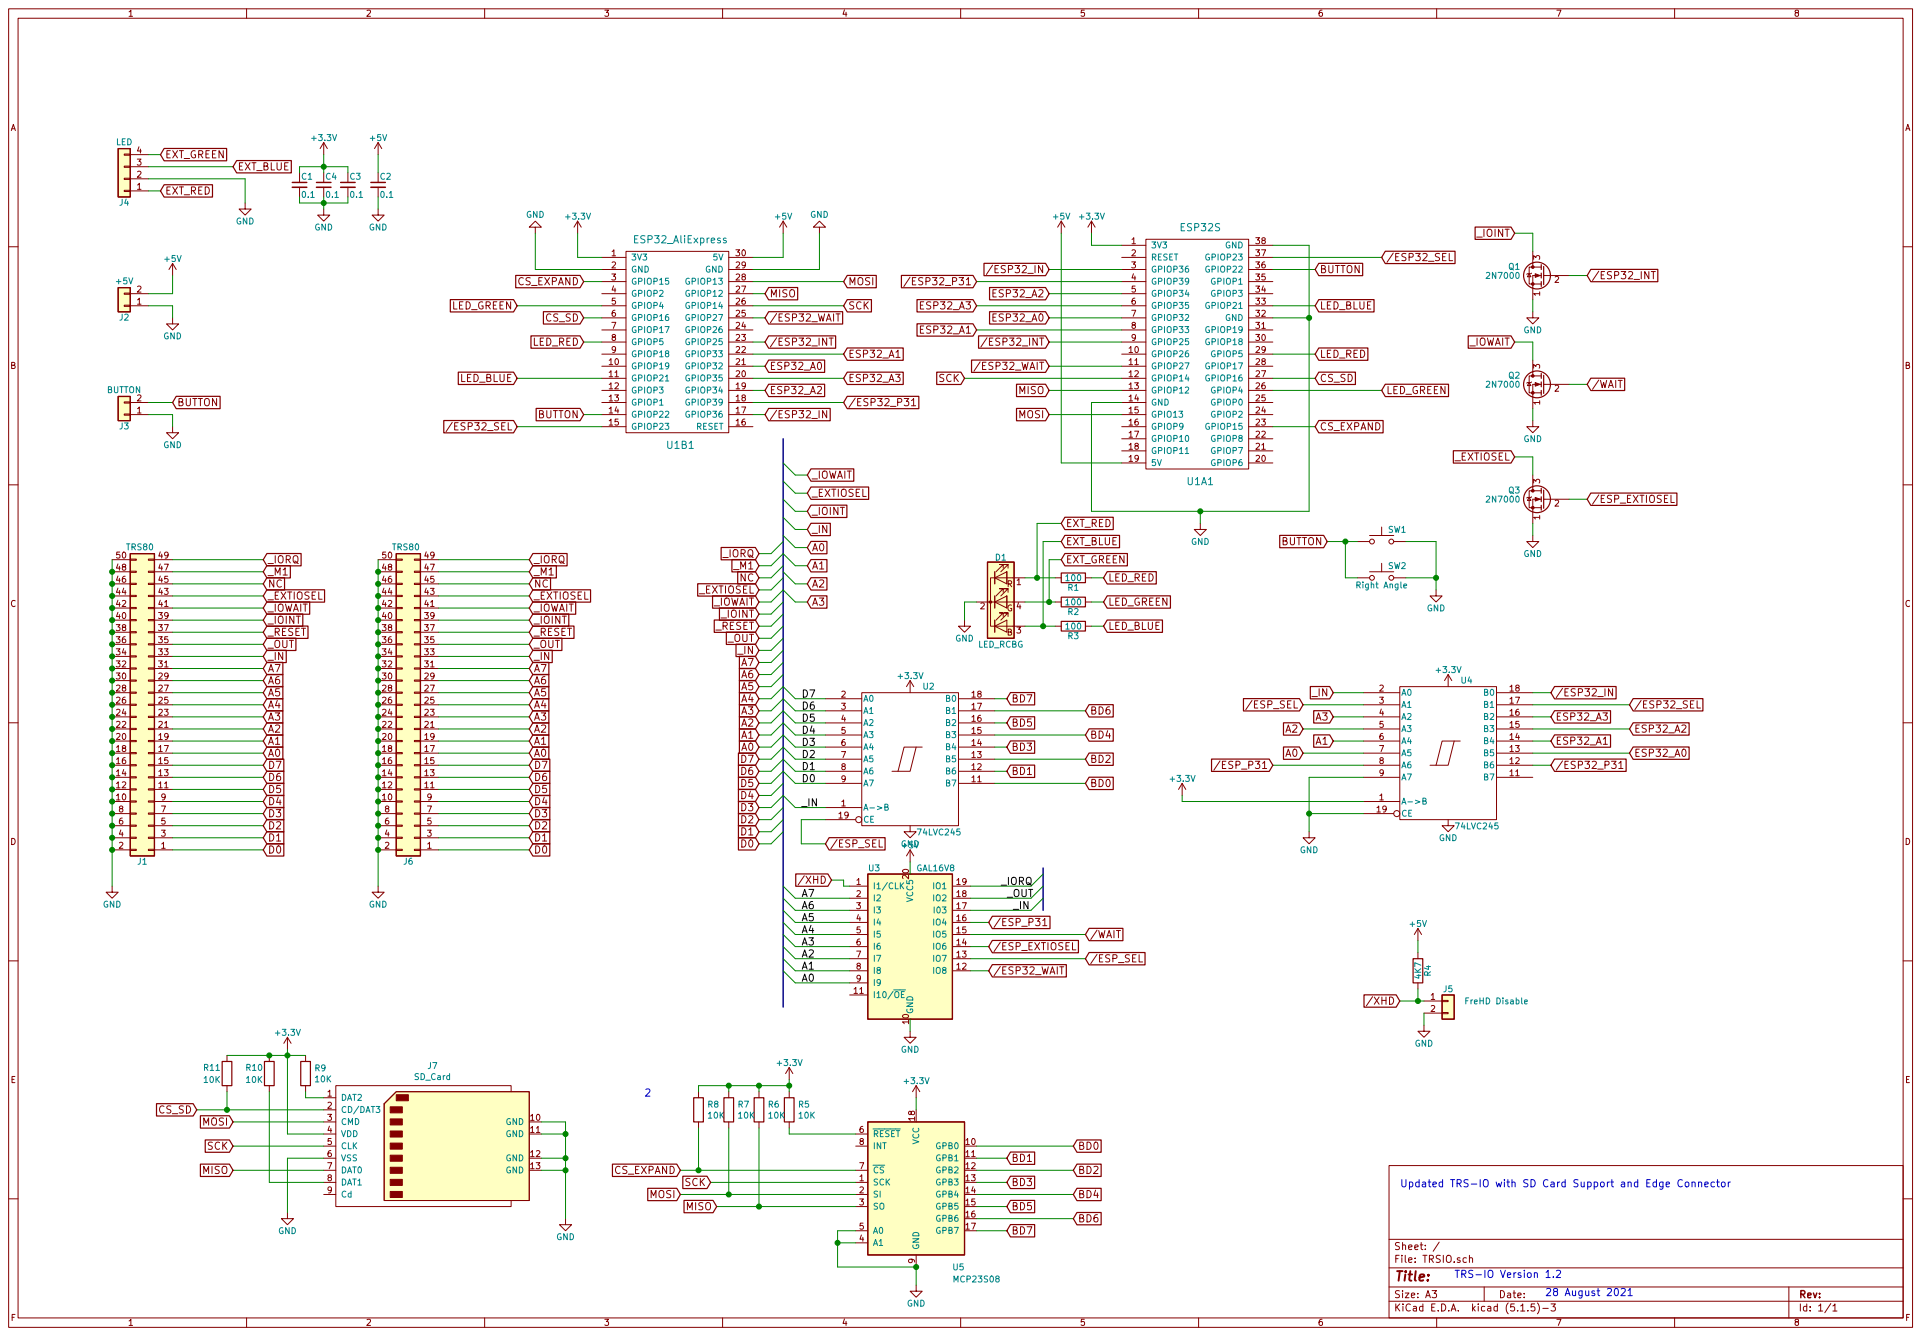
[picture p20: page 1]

I2 2 | _OUT
I3 3 | _IN

Id: 1/1 Title: File: TRSIO.sch Sheet: /

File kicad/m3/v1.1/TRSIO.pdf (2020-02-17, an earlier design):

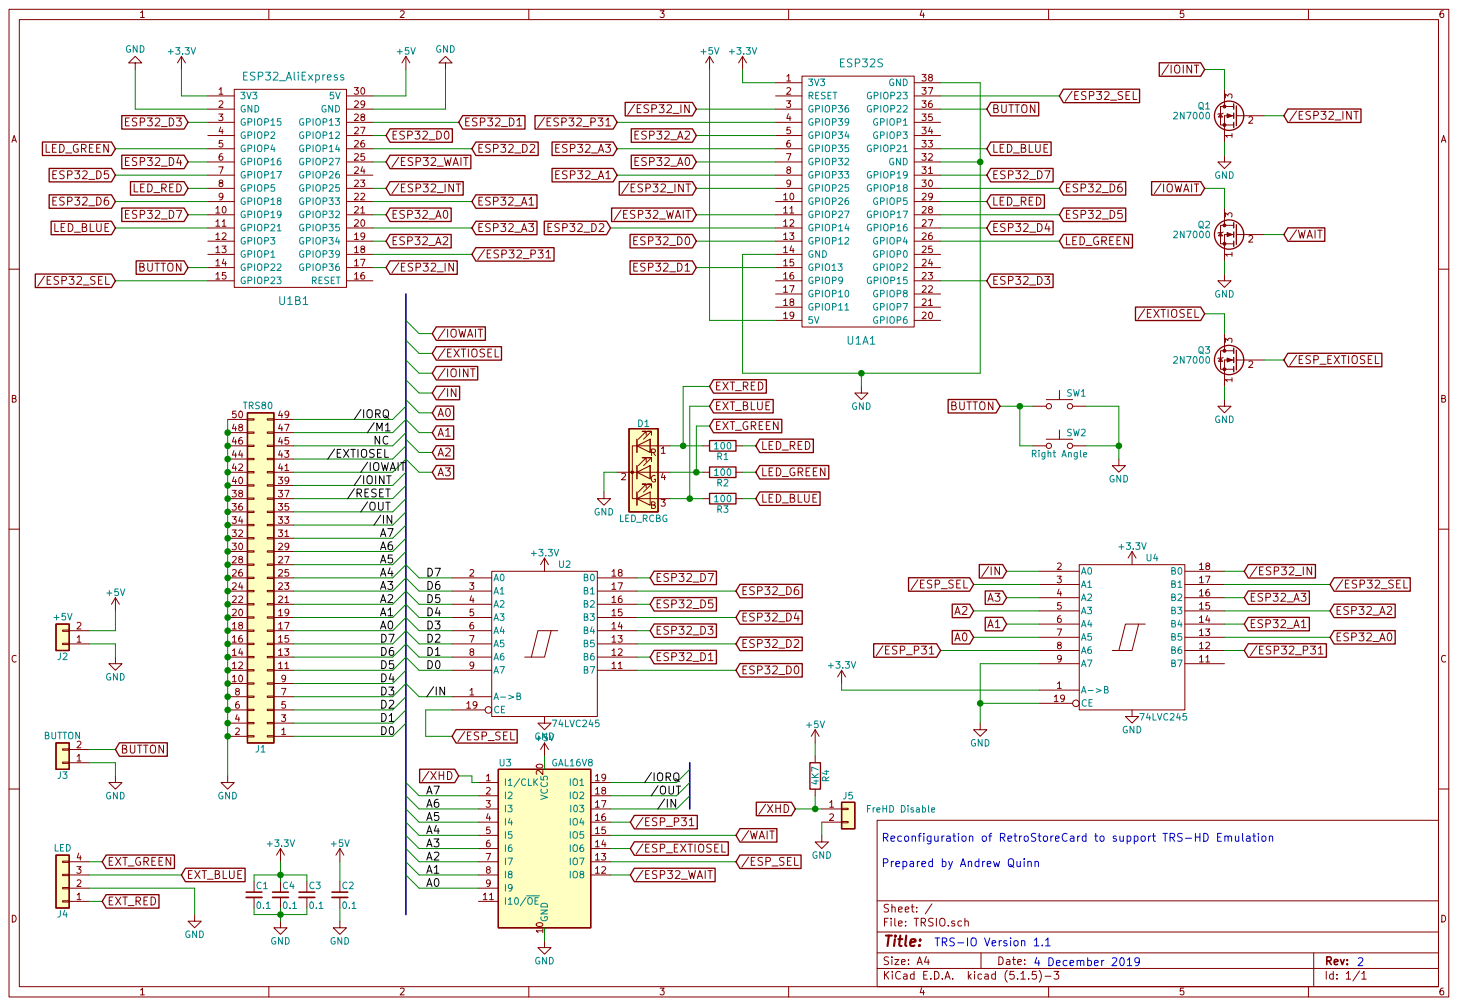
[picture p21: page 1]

48 | /M1 47
46 | 45
44 | 43
28 | /IOWAIT D0 D1A3 /IOINTA1A0D6 D5 D4 D3 D2 27
42 | 41
40 | 39
38 | /RESET 37
36 | 35 /OUT
34 | /IN 33
32 | 31
30 | 29

Id: 1/1 Title: File: TRSIO.sch Sheet: / BG

24 | 23
22 | 21
20 | 19
18 | 17
16 | 15
14 | 13
12 | 11
10 | 9

2 Reconfiguration of RetroStoreCard to support TRS-HD Emulation

Prepared by Andrew Quinn

4 December 2019 TRS-IO Version 1.1

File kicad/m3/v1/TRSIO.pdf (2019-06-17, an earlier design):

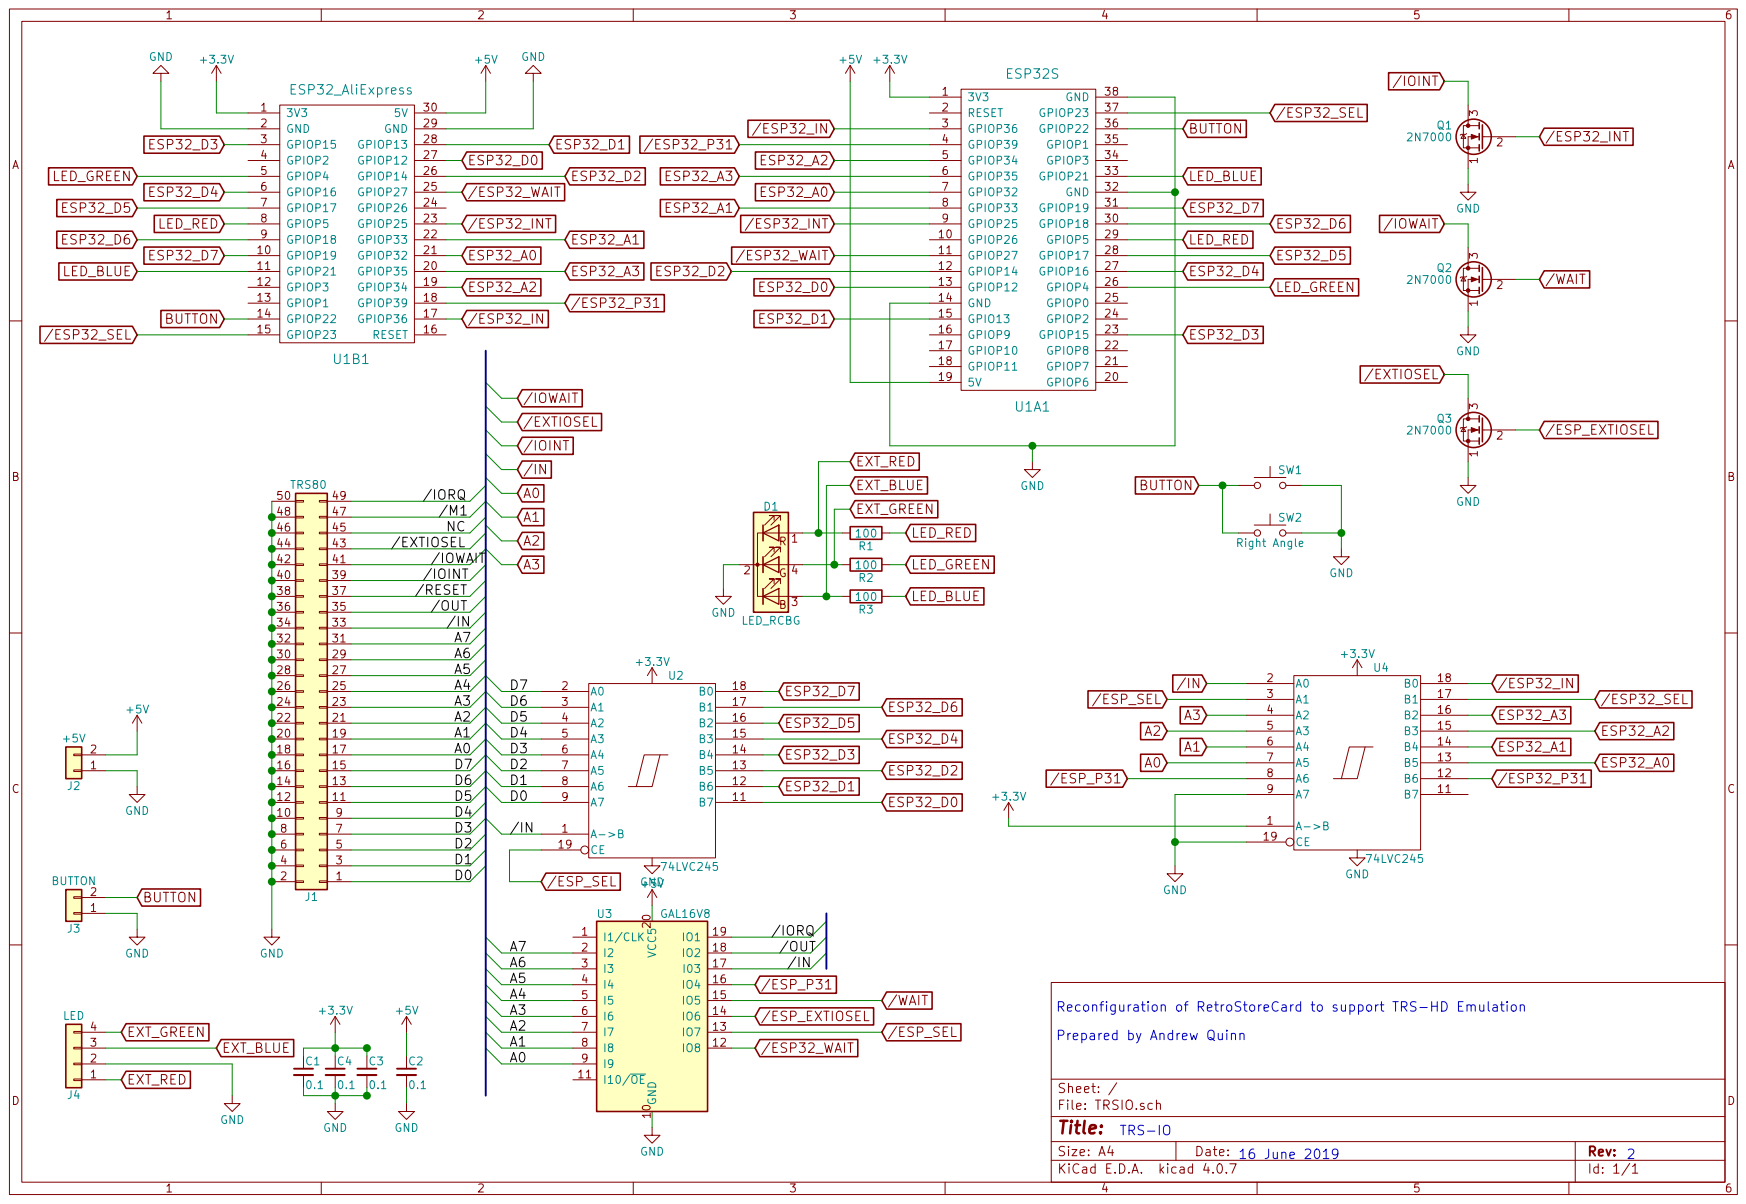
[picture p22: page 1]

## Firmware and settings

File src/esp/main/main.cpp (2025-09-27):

#include "sdkconfig.h"
#include "io.h"
#include "led.h"
#include "button.h"
#include "wifi.h"
#include "http.h"
#include "ota.h"
#include "settings.h"
#include "event.h"
#include "esp_event.h"
#include "esp_log.h"
#include "esp_system.h"
#include "esp_spi_flash.h"
#include "esp32/spiram.h"
#include "esp_ota_ops.h"
#include "esp_efuse.h"
#include "esp_efuse_table.h"
#include "trs-io.h"
#include "trs-fs.h"
#include "spi.h"
#include "keyb.h"
#include "ptrs.h"
#include "xflash.h"
#include "spiffs.h"

#include "esp_idf_version.h"

#if ESP_IDF_VERSION != ESP_IDF_VERSION_VAL(4, 4, 7)
#error Please use ESP-IDF version 4.4.7
#endif

#define TAG "TRS-IO"

#ifdef CONFIG_TRS_IO_MODEL_1
#define CONFIG "TRS-IO (Model 1)"
#endif
#ifdef CONFIG_TRS_IO_MODEL_3
#define CONFIG "TRS-IO (Model III)"
#endif
#ifdef CONFIG_TRS_IO_PP
#ifdef CONFIG_MINI_TRS
#define CONFIG "MiniTRS"
#else
#define CONFIG "TRS-IO++"
#endif
#endif

extern const char* GIT_REV;
extern const char* GIT_BRANCH;


static void check()
{
#ifdef CONFIG_TRS_IO_PP  
  bool force = esp_efuse_read_field_bit(ESP_EFUSE_SDIO_FORCE);
  bool reg   = esp_efuse_read_field_bit(ESP_EFUSE_XPD_SDIO_REG);
  bool tieh  = esp_efuse_read_field_bit(ESP_EFUSE_SDIO_TIEH);

  ESP_LOGI(TAG, "Checking hardware configuration...");

  if (force && reg && tieh) {
    ESP_LOGI(TAG, "Flash regulator forced to 3.3V");
  } else {
    ESP_LOGE(TAG, "Flash regulator NOT forced to 3.3V");
  }

  size_t flash_size = spi_flash_get_chip_size() / (1024 * 1024);
  size_t psram_size = esp_spiram_get_size() / (1024 * 1024);

  if (flash_size == 16) {
    ESP_LOGI(TAG, "Found 16MB flash size");
  } else {
    ESP_LOGE(TAG, "Flash size needs to be configured to 16MB. Found %dMB", flash_size);
  }
  if (psram_size == 8) {
    ESP_LOGI(TAG, "Found 8MB of PSRAM");
  } else {
    ESP_LOGE(TAG, "Need 8MB of PSRAM. Found %dMB", psram_size);
  }

  const esp_partition_t* running = esp_ota_get_running_partition();
  esp_ota_img_states_t ota_state;
  if (esp_ota_get_state_partition(running, &ota_state) == ESP_OK) {
      if (ota_state == ESP_OTA_IMG_PENDING_VERIFY) {
        // Assume everything is peachy just because we made it here
        ESP_LOGI(TAG, "Marking OTA update as valid");
        esp_ota_mark_app_valid_cancel_rollback();
      }
  }
  ESP_LOGI(TAG, "Running partition: %s", running->label);
#endif
}

extern "C" {

void app_main(void)
{
  ESP_LOGI(TAG, "TRS-IO branch=%s, rev=%s", GIT_BRANCH, GIT_REV);
  ESP_LOGI(TAG, "Configured for %s", CONFIG);

  // Silence "spi_master: device5 locked the bus" debug messages when
  // accessing the SD card.
  esp_log_level_set("spi_master", ESP_LOG_INFO);

  check();

  init_events();
  init_trs_io();
  init_button();
  init_settings();
  init_spi();
  init_led();
  init_trs_fs_posix();
  init_spiffs();
#ifdef CONFIG_TRS_IO_PP
#ifdef CONFIG_MINI_TRS
  // For MiniTRS, wait 6 seconds to keep the splash screen
  vTaskDelay(6000 / portTICK_PERIOD_MS);
#else
  init_keyb();
#endif
#endif
  init_fpga();
  init_wifi();
  init_io();
  init_http();

  vTaskDelete(NULL);
}

} // extern "C"

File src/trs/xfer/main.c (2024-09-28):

#include <trs-io.h>
#include <dos.h>
#include <inout.h>
#include <key.h>
#include <stdio.h>
#include <stdarg.h>
#include <xfer-params.h>


static const char* commands[] = {
  "DIR",
  "OPEN",
  "INIT",
  "READ",
  "WRITE",
  "CLOSE",
  "REMOVE",
  "RENAME"
};


static xfer_in_t in;
static xfer_out_t out;

static fcb_t fcb;
static uint16_t ern;

static bool quiet = false;

static void log(const char* fmt, ...)
{
  va_list argp;

  if (quiet) {
    return;
  }

  va_start(argp, fmt);
  vprintf(fmt, argp);
  va_end(argp);
}

static void usage()
{
  printf("Usage: xfer [-q]\n");
  printf("    -q: Quiet mode\n");
}

static void start_xfer()
{
  log("Starting XFER server\n");
  out31(XFER_MODULE_ID);
  out31(XFER_START);
  wait_for_esp();
}

static void stop_xfer()
{
  log("Stopping XFER server\n");
  out31(XFER_MODULE_ID);
  out31(XFER_STOP);
  wait_for_esp();
}

static uint16_t process_cmd_dir(cmd_in_dir_t* in, cmd_out_dir_t* out)
{
  dos_err_t err = dos_ramdir(0, in->drive, &out->entries);
  out->err = err;
  if (err != 0) {
    return 1;
  }
  uint16_t n = 0;
  while(out->entries[n].fname[0] != '+') {
    n++;
  }
  out->n = n;
  uint16_t size = n * sizeof(dir_t);
  return 1 + sizeof(n) + size;
}

static uint16_t process_cmd_open(cmd_in_open_t* in, cmd_out_open_t* out)
{
  dos_err_t err = dos_fspec(&in->fn[0], &fcb);
  if (err != NO_ERR) {
    out->err = err;
    return 1;
  }
  err = dos_open(&fcb, &((cmd_out_read_t*) out)->sector, 0);
  if (err != NO_ERR && err != ERR_LRL) {
    out->err = err;
    return 1;
  }

  ern = dos_getern(&fcb);
  out->err = NO_ERR;
  return 1;
}

static uint16_t process_cmd_init(cmd_in_init_t* in, cmd_out_init_t* out)
{
  dos_err_t err = dos_fspec(&in->fn[0], &fcb);
  if (err != NO_ERR) {
    out->err = err;
    return 1;
  }
  err = dos_init(&fcb, &((cmd_in_write_t*) in)->sector, 0);
  if (err != NO_ERR && err != ERR_LRL) {
    out->err = err;
    return 1;
  }

  ern = dos_getern(&fcb);
  out->err= NO_ERR;
  return 1;
}

static uint16_t process_cmd_read(cmd_in_read_t* in, cmd_out_read_t* out)
{
  (void) in;
  out->count = 0;
  out->err = NO_ERR;
  if (ern != 0) {
    ern--;
    uint8_t err = dos_read(&fcb, NULL);
    if (err != NO_ERR) {
      out->err = err;
      return 1;
    }
    out->count = (ern == 0) ? fcb.fname[8] : 256;
    if (out->count == 0) {
      out->count = 256;
    }
    return sizeof(cmd_out_read_t);
  }
  return 1 + sizeof(uint16_t);
}

static uint16_t process_cmd_write(cmd_in_write_t* in, cmd_out_write_t* out)
{
  dos_err_t err = dos_write(&fcb, NULL);
  if (err != NO_ERR) {
    out->err = err;
    return 1;
  }
  // Set EOF
  fcb.fname[8] = (in->count) & 0xff;
  dos_setern(&fcb);
  out->err = NO_ERR;
  return 1;
}

static uint16_t process_cmd_close(cmd_in_close_t* in, cmd_out_close_t* out)
{
  (void) in;
  out->err = dos_close(&fcb);
  return 1;
}

static uint16_t process_cmd_remove(cmd_in_remove_t* in, cmd_out_remove_t* out)
{
  dos_err_t err = dos_fspec(&in->fn[0], &fcb);
  if (err != NO_ERR) {
    out->err = err;
    return 1;
  }
  err = dos_open(&fcb, NULL, 0);
  if (err != NO_ERR && err != ERR_LRL) {
    out->err = err;
    return 1;
  }
  out->err = dos_remove(&fcb);
  return 1;
}

static uint16_t process_cmd_rename(cmd_in_rename_t* in, cmd_out_rename_t* out)
{
  out->err = dos_rename(&in->from[0], &in->to[0]);
  return 1;
}

static void process_cmd()
{
  uint16_t len = 0;

  log(commands[in.cmd]);
  if (in.cmd == XFER_CMD_OPEN) {
    log(": %.15s", in.params.open.fn);
  }
  if (in.cmd == XFER_CMD_INIT) {
    log(": %.15s", in.params.init.fn);
  }
  if (in.cmd == XFER_CMD_RENAME) {
    log(": %.15s -> %.15s", in.params.rename.from, in.params.rename.to);
  }
  log("\n");

  out31(XFER_MODULE_ID);
  out31(XFER_SEND_RESULT);

  switch(in.cmd) {
    case XFER_CMD_DIR:
      len = process_cmd_dir(&in.params.dir, &out.dir);
      break;
    case XFER_CMD_OPEN:
      len = process_cmd_open(&in.params.open, &out.open);
      break;
    case XFER_CMD_INIT:
      len = process_cmd_init(&in.params.init, &out.init);
      break;
    case XFER_CMD_READ:
      len = process_cmd_read(&in.params.read, &out.read);
      break;
    case XFER_CMD_WRITE:
      len = process_cmd_write(&in.params.write, &out.write);
      break;
    case XFER_CMD_CLOSE:
      len = process_cmd_close(&in.params.close, &out.close);
      break;
    case XFER_CMD_REMOVE:
      len = process_cmd_remove(&in.params.remove, &out.remove);
      break;
    case XFER_CMD_RENAME:
      len = process_cmd_rename(&in.params.rename, &out.rename);
      break;
  }
  // Send result to ESP
  out31(len & 0xff);
  out31(len >> 8);
  uint8_t* raw = (uint8_t*) &out;
  for (int i = 0; i < len; i++) {
    out31(*raw++);
  }
  wait_for_esp();
}

static void run_server()
{
  while(true) {
    out31(XFER_MODULE_ID);
    out31(XFER_NEXT_CMD);
    while (!is_esp_done()) {
      if (scan_key() == KEY_BREAK) {
        log("User abort\n");
        return;
      }
    }
    uint8_t bl = in31();
    uint8_t bh = in31();
    uint16_t len = bl | (bh << 8);
    if (len > sizeof(in)) {
      log("ERROR: command is too long (%d bytes)\n", len);
      continue;
    }
    uint8_t* raw = (uint8_t*) &in;
    for (int i = 0; i < len; i++) {
      *raw++ = in31();
    }
    process_cmd();
  }
}

int main(const char* args)
{
  if (strcmp(args, "-q") == 0) {
    quiet = true;
  } else if (args[0] != '\0') {
    usage();
    return -1;
  }

  if (trs_io_status() == TRS_IO_STATUS_NO_TRS_IO) {
    log("No TRS-IO card found!\n");
    return -1;
  }

  start_xfer();
  run_server();
  stop_xfer();
  return 0;
}

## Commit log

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2018-04-05 Support for IOBUSINT and push button
    [RetroStore.fzz]
2018-04-06 Added fritzing for push button and control for IOBUSINT
    [RetroStore.fzz]
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2018-06-22 Fix for query support. WiFi support. Check for RetroStore card
    [io.c, main.c]
2018-06-23 Fix for aborting root menu
    [main.c]
2018-12-28 v1.1 macOS build and add /dist dir
    [RetroStore.fzz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]
2018-12-31 Add 3d directory and stl file for PCB v1.1
    [pcb_case.stl]
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2019-02-23 Fix TRS-IO init bug
    [main.cpp]
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2019-06-17 Added Kicad V1 Layout
    [TRSIO-B.Cu.gbr, TRSIO-B.Mask.gbr, TRSIO-B.SilkS.gbr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]
2019-07-06 Gerber Updates
    Regenerated Gerbers for button position.
    Removed -bak file.
    [TRSIO-B.Cu.gbr, TRSIO-B.Mask.gbr, TRSIO-B.SilkS.gbr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]
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2019-08-27 Disable intr for LED(!) to avoid runtime errors
    [led.cpp]
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2019-09-01 Add 'waiting...' message when TRS-IO is unavailable.
    Also avoid requests to the device to overlap, thus over loading the device.
2019-09-07 Fix for RSC PCB compat setting
    [io.cpp, led.cpp]
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2019-12-21 Updated PCB to support FreHD Disable
    PCB updates as follows:
    1. LED moved for better clearance when using the HILETGO ESP module with USB power.
    2. Pullup on U3 Pin 1. Jumper to GND to disable FreHD functionality when using TRS-IO with other modules that provide hard disk emulation.
    [TRSIO-B.Cu.gbr, TRSIO-B.Mask.gbr, TRSIO-B.SilkS.gbr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]
2020-02-17 1. Update schematic PDF to correctly show version 1.1. changes
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2020-02-19 1. Correct path to ESP32 module images
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2021-02-04 Added GAL and KiCad files for the M1
    [TRS-IO-M1-B_Cu.gbr, TRS-IO-M1-B_Mask.gbr, TRS-IO-M1-B_SilkS.gbr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]
2021-02-04 Remove Fritzing and dist files
    [RetroStore.fzz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]
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2021-02-04 Fix race condition with heartbeat interrupt
    [io.cpp]
2021-02-04 Fixes for ESP-IDF 3.3.3
    [io.cpp, main.cpp]
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2021-06-23 Copy KiCad v1 to v1.1
    [TRS-IO-M1-B_Cu.gbr, TRS-IO-M1-B_Mask.gbr, TRS-IO-M1-B_SilkS.gbr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]
2021-06-28 Updates for TRS-IO-M1 v1.1
    - Move data bus of the SRAM before the buffer
    - added J2 for the edge connector
    - Removed ADDR_2 and repurposed the connection for RAS*
    - Move ESP_SEL_N to GPIO 27
    - Move ESP_WAIT_RELEASE_N to GPIO 2
    [TRS-IO-M1-B_Cu.gbr, TRS-IO-M1-B_Mask.gbr, TRS-IO-M1-B_SilkS.gbr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]
2021-07-13 Adjust GPIO assignment to PCB v1.1
    [partitions.csv]
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2021-07-20 TRS-IO-M1 PCB v1.2 (adding SD card)
    [TRS-IO-M1-B_Cu.gbr, TRS-IO-M1-B_Mask.gbr, TRS-IO-M1-B_SilkS.gbr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]
2021-08-27 Updated M3 for compatibility with Kicad 5.1.5
    [TRSIO.kicad_pcb, TRSIO.sch]
2021-08-28 TRS-IO-M3 PCB v1.2
    1. Project cleanup for compatibility with Kicad 5.1.x
    2. Added Edge connector.
    [TRSIO-B.Cu.gbr, TRSIO-B.Mask.gbr, TRSIO-B.SilkS.gbr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]
2021-08-29 TRS-IO-M3 PCB v1.2 + SD Card
    Schematic updates only. PCB still outstanding
    [TRSIO.sch]
2021-08-29 TRS-IO-M3 PCB v1.2 + SD Card + PCB Updates
    1. Connect GND pins of the SD card to ground
    2. SPI pins connected for ESP32S
    3. Pullup for CS_SD
    4. PCB Layout
    [TRSIO-B_Cu.gbr, TRSIO-B_Mask.gbr, TRSIO-B_SilkS.gbr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]
2021-08-29 TRS-IO-M3 PCB v1.2 + SD Card + PCB Updates
    1. Updated labels for buffered data bus signals from ESP32_Dx to BDx.
    2. Updated meta data on schematic and PCB
    3. Added M3 mounting holes to PCB
    [TRSIO-B_Cu.gbr, TRSIO-B_Mask.gbr, TRSIO-B_SilkS.gbr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]
2021-08-29 TRS-IO-M3 PCB v1.2 + SD Card + PCB Updates
    1. Added pin number labels to the edge connector.
    2. Added alignment holes below the SD Card.
    [TRSIO-B_Cu.gbr, TRSIO-B_Mask.gbr, TRSIO-B_SilkS.gbr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]
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2021-12-31 TRS-IO-M1 using FPGA This commit is an FPGA version of TRS-IO-M1. It is functionally equivalent to TRS-IO-M1. The FPGA uses BRAM for the upper 32KB of RAM, supports autoboot via a FDC boot sector, su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
    [io-xray.cpp, spi-xray.cpp, spi.h]
2022-01-01 Update TRS-IO-XRAY to KiCad 6
    [TRS-IO-M1.kicad_pcb, TRS-IO-M1.kicad_sch]
2022-01-14 Add VGA to TRS-IO-XRAY schematics and PCB
    [TRS-IO-M1-B_Cu.gbr, TRS-IO-M1-B_Mask.gbr, TRS-IO-M1-B_Silkscreen.gbr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]
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2022-02-06 Make sure that context saved in XRAM is always correct
    [io-xray.cpp]
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2022-04-23 Fix crash when TRS-IO is not initialized
    [io.c]
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2022-05-06 Fix for case-insensitive filesystems
2022-05-09 Tang Nano 9K version
    [TRS-IO-M1-B_Cu.gbr, TRS-IO-M1-B_Mask.gbr, TRS-IO-M1-B_Silkscreen.gbr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]
2022-05-13 PCB for TRS-IO-XRAY 1.3 (Nano 9K)
    [TRS-IO-M1-B_Cu.gbr, TRS-IO-M1-B_Mask.gbr, TRS-IO-M1-B_Silkscreen.gbr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]
2022-05-26 Nano 9K version for 32K BRAM (not working)
    [device.cfg]
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2022-06-12 PCB updates for TRS-IO-M1 1.3
    [TRS-IO-M1-B_Cu.gbr, TRS-IO-M1-B_Mask.gbr, TRS-IO-M1-B_Silkscreen.gbr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]
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2022-06-14 Updated Gerber files for TRS-IO-M1 1.3-xray
    [TRS-IO-M1-B_Cu.gbr, TRS-IO-M1-B_Mask.gbr, TRS-IO-M1-B_Silkscreen.gbr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]
2022-06-14 PCB version for the Videogenie
    [TRS-IO-M1-B_Cu.gbr, TRS-IO-M1-B_Mask.gbr, TRS-IO-M1-B_Silkscreen.gbr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]
2022-07-26 PCB version for TRS-IO-M3 using Nano 9K (v2.0)
    [TRS-IO-M3-B_Cu.gbr, TRS-IO-M3-B_Mask.gbr, TRS-IO-M3-B_Silkscreen.gbr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]
2022-07-31 Fixes for ESP-IDF 4.4.1
    [spi-xray.cpp]
2022-08-10 FPGA version for TRS-IO-M3 (Verilog only)
    [device.cfg]
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2022-08-24 TRS-IO-M3 silkscreen fixes
    [TRS-IO-M3-B_Cu.gbr, TRS-IO-M3-B_Mask.gbr, TRS-IO-M3-B_Silkscreen.gbr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]
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2022-09-24 Initial XRAY support for M1 (not working; mem overflow)
    [io.cpp]
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2022-10-05 Move Verilog code to m1 directory
    [device.cfg]
2022-10-05 Verilog for vg v2.0
    [device.cfg]
2022-11-19 Fix for broken breakpoint trigger
    [device.cfg]
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2023-02-03 KiCad files for TRS-IO++ v0.1 (formerly NextTRS)
    [NextTRS-B_Cu.gbr, NextTRS-B_Mask.gbr, NextTRS-B_Paste.gbr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]
2023-02-03 KiCad files for TRS-IO++ v0.2
    [TRS-IO++-B_Cu.gbr, TRS-IO++-B_Mask.gbr, TRS-IO++-B_Paste.gbr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]
2023-02-05 Move diagnostic LEDs to PCB edge
    [TRS-IO++-B_Cu.gbr, TRS-IO++-B_Mask.gbr, TRS-IO++-B_Paste.gbr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]
2023-02-05 Imported TRS-IO++ Verilog from NextTRS
    [device.cfg]
2023-02-14 Fix GPIO pin assignments for TRS-IO++
    [io.cpp]
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2023-02-19 Route JTAG TDI/TDO to different GPIOs
    [TRS-IO++-B_Cu.gbr, TRS-IO++-B_Mask.gbr, TRS-IO++-B_Paste.gbr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]
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2023-03-17 Add RC circuit for ESP reset
    [TRS-IO++-B_Cu.gbr, TRS-IO++-B_Mask.gbr, TRS-IO++-B_Paste.gbr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]
2023-03-17 Change R of RC reset circuit to 10K
    [TRS-IO++-B_Cu.gbr, TRS-IO++-B_Mask.gbr, TRS-IO++-B_Paste.gbr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]
2023-03-18 improved ground plane on pcb
    [TRS-IO++.kicad_pcb]
2023-03-18 Redo ground fill. Generate Gerber files
    [TRS-IO++-B_Cu.gbr, TRS-IO++-B_Mask.gbr, TRS-IO++-B_Paste.gbr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]
2023-03-19 Fix +3V3 net
    [TRS-IO++-B_Cu.gbr, TRS-IO++-B_Mask.gbr, TRS-IO++-B_Paste.gbr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]
2023-03-20 Fixed missing connection in schematic. Small pcb cleanup.
    [TRS-IO++-B_Cu.gbr, TRS-IO++-B_Mask.gbr, TRS-IO++-B_Paste.gbr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]
2023-04-06 Copy FPGA pp/v0.2 to pp/v0.3
    [device.cfg]
2023-04-07 Add FPGA support for M3
    [device.cfg]
2023-04-09 Integration of NextTRS (not working)
    [io.cpp, spi.cpp, spi.h]
2023-04-21 Fix timing issues for NextZ80 and reset button
    [button.cpp]
2023-04-26 Fix reset button
2023-04-30 Minor layout changes for TRS-IO-M3
    [TRS-IO-M3-B_Cu.gbr, TRS-IO-M3-B_Mask.gbr, TRS-IO-M3-B_Silkscreen.gbr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]
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2023-05-20 Improved grounding around M1 connector. Added resistor to cassette circuit for mid-level output.
    [TRS-IO++-B_Cu.gbr, TRS-IO++-B_Mask.gbr, TRS-IO++-B_Paste.gbr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]
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2023-06-06 Fix for internal interrupt
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2023-09-08 Support for ptrs reset (ESP side)
    [button.cpp, io.cpp]
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2023-10-11 Move UART traces to upper layer of PCB
    [TRS-IO++-B_Cu.gbr, TRS-IO++-B_Mask.gbr, TRS-IO++-B_Paste.gbr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]
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2023-12-25 Compilation fix for M1 and MIII
    [io.cpp]
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2024-01-17 Route all printer requests to the ESP (not working)
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2024-02-12 TRS-IO-M3: Simplifed SPI interface. Removed address valid flag. Added reset to ESP interface. Reduced clock to 84MHz.
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2024-03-21 Show solid heartbeat LED when encountering a SPI protocol error
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2024-04-24 Fix for RSHIFT. Support for keypad (reported by gituserkj)
    [keyb.cpp]
2024-04-24 Check for correct ESP-IDF version at compile time
    [main.cpp]
2024-04-24 Fix for locked F5 when changing Wifi credentials
    [ptrs.cpp]
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2024-05-14 Fixed reliability issue with long-press ROM download
    [io.cpp, ptrs.cpp, spi.cpp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]
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2024-06-07 Have ESP upload correct bitstream to FPGA
    [partitions-pp.csv]
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2024-06-11 TRS-IO++: ptrs-m4/4p Added missing wire definitions for cassette out.
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2024-06-21 Fix for TRS-IO++ silkscreen
    [TRS-IO++.kicad_pcb]
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2024-07-15 Webapp: Use correct device type in header.
2024-09-01 Fix deadlock with POSIX. Add thread safety to SMB
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2024-09-08 Bump max files for html partition from 2 to 10.
    [partitions-pp.csv]
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2024-10-01 Reduce short button press threshold to 500ms
    [button.cpp]
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2024-10-13 Fix for stuck PS/2 keyboard
    [io.cpp, keyb.cpp, ptrs.cpp]
2024-10-13 Always call PS2Controller.end() on reboot
    [keyb.cpp]
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2024-10-27 Set status LED to blue during factory reset
    [main.cpp]
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2024-12-16 Compress files in HTML partition to fit in SPIFFS.
    This commits makes several changes:
    1. Splits sdkconfig.trs-io-pp into three files, one for
    TRS-IO M1, one for TRS-IO M3, and one for TRS-IO++.
    2. Pulls their common elements into a generic TRS-IO sdkconfig file.
    3. Renames the non-PP partition file to m1-m3 for clarification.
    4. Shrinks the PP "html" partition to 200 kB (from 2 MB) to match the
    non-PP one, so that we can catch errors while developing for ++, and
    to make flashing faster.
    5. Updates the Makefile to use the right sdkconfig files depending
    on the BOARD variable (see instructions at the top of the Makefile).
    6. Moves the "html" directory one level up, outside t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
    [partitions-m1-m3.csv, partitions-pp.csv]
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
